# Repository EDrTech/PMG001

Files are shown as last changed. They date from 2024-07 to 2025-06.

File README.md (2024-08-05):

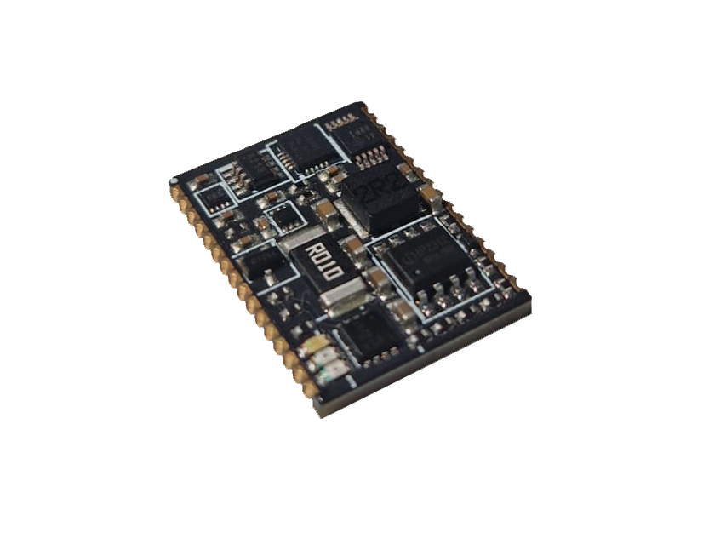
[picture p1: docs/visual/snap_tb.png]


# PMG001 Power management module

The PMG001 is a highly integrated module designed for efficient management of single-cell
Li-Po battery systems. It incorporates various essential ICs to address all aspects of power
management, including battery charging, switch/button power on/off behavior, undervoltage
and overvoltage protection, flexible voltage measurement, battery current measurement, and
temperature monitoring. Additionally, it features a microcontroller for programming custom
behaviors, ensuring comprehensive management of single-cell rechargeable battery
systems.
Furthermore, when paired with the demo kit base PCB, the module serves as a general
development board for the ATTINY1616, with all
1 pins accessible for any application.

## Features

- 32 PIN 22.22mm *16.51mm package
- On/off behavior control
- 2A single cell charger
- Single li-po cell powered
- 4+16 ADC channels
- Bi-directional battery current measurement
- Brown-out detection/reset circuit
- Low RDSon battery output MOSFET
- On-module temperature measurement
- I2C Interface
- Arduino compatible

## Installation

To program this module you will need the following:

- Arduino DE (Or other IDE of your choosing)
- [megaTinyCore](https://github.com/SpenceKonde/megaTinyCore)
- Demo kit with the module soldered on

There's no need to install any additional libraries as the example code only uses the wire library to handle I2C, the rest is in the [example](pmg001_default/pmg001_default.ino) code. Keep in mind that some register values are hardcoded, which is not the best way to handle something like that but is done here for the sake of simplicity. You can use external libraries with this module without issues, you just need to redefine I2C adresses of devices as they don't necessarily match with other libraries.

Board settings should be set up like this:

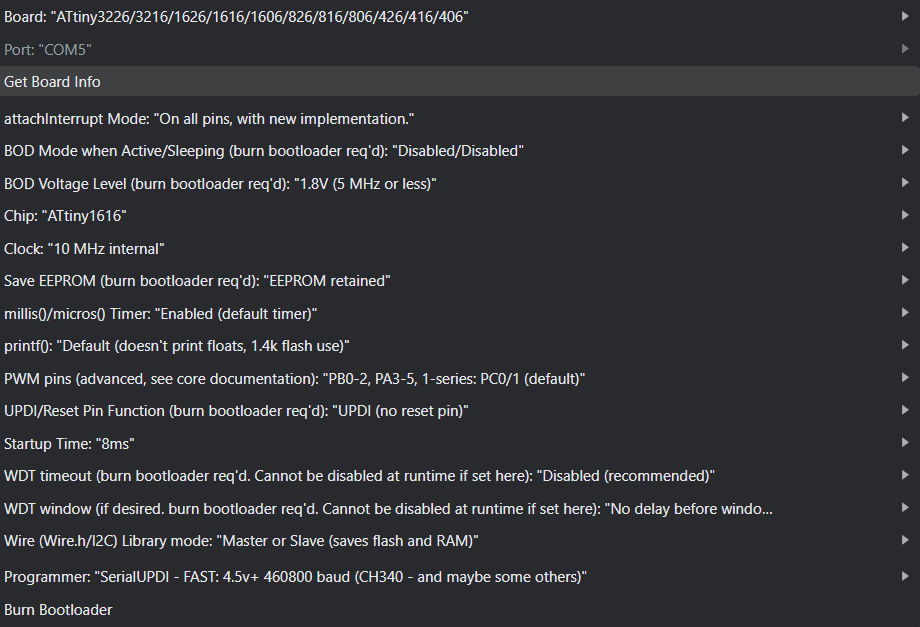
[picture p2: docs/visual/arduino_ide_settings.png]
Arduino IDE board settings


Default code provides basic power management and monitoring - press PWR_SW for >500ms and BAT_OUT will turn on, hold PWR_SW for >3s and BAT_OUT will turn off.

For more information, please read the [datasheet](PMG001_datasheet.pdf).

## Module Schematic

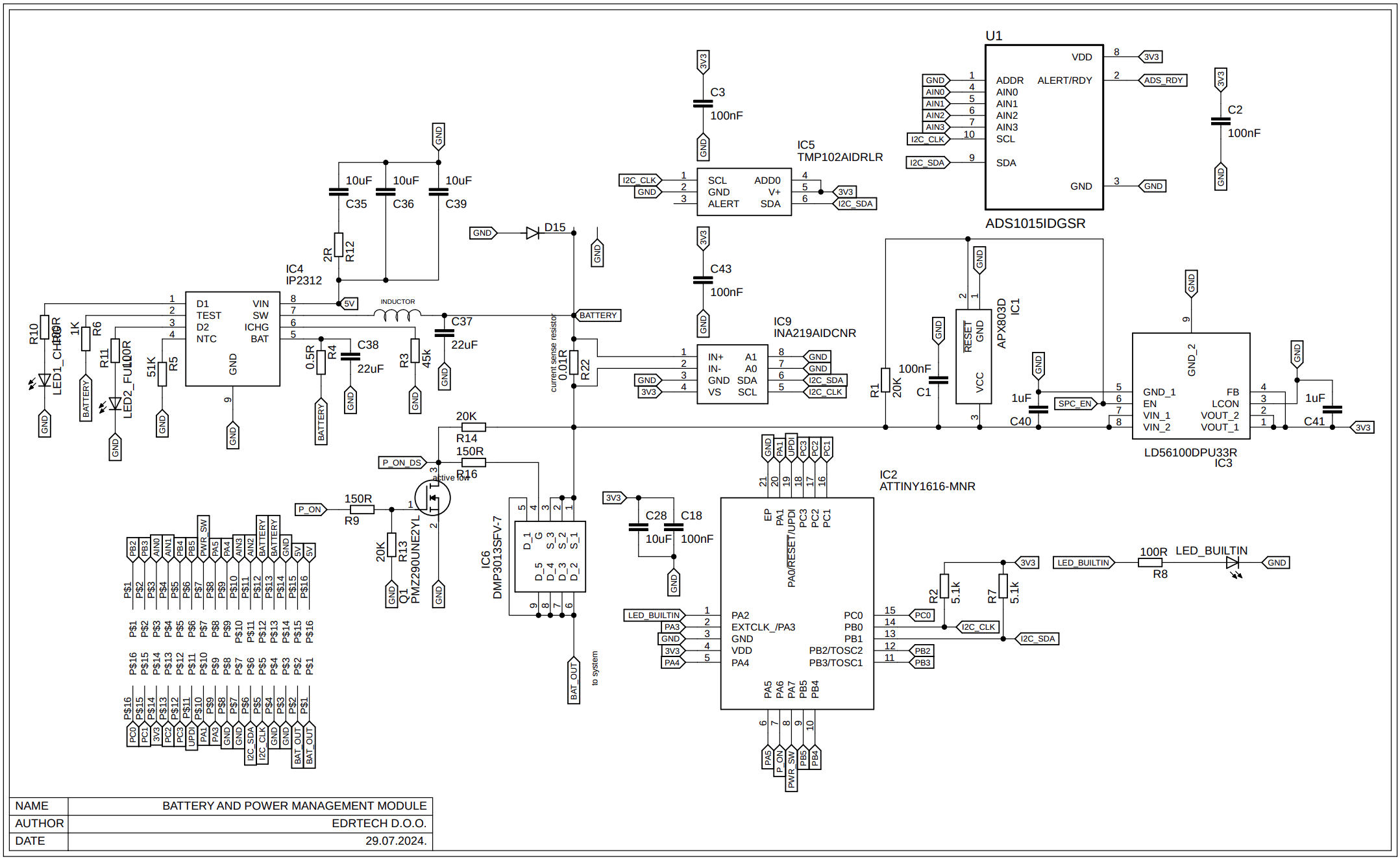
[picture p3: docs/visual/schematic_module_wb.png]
Module schematic


## Breakout board Schematic

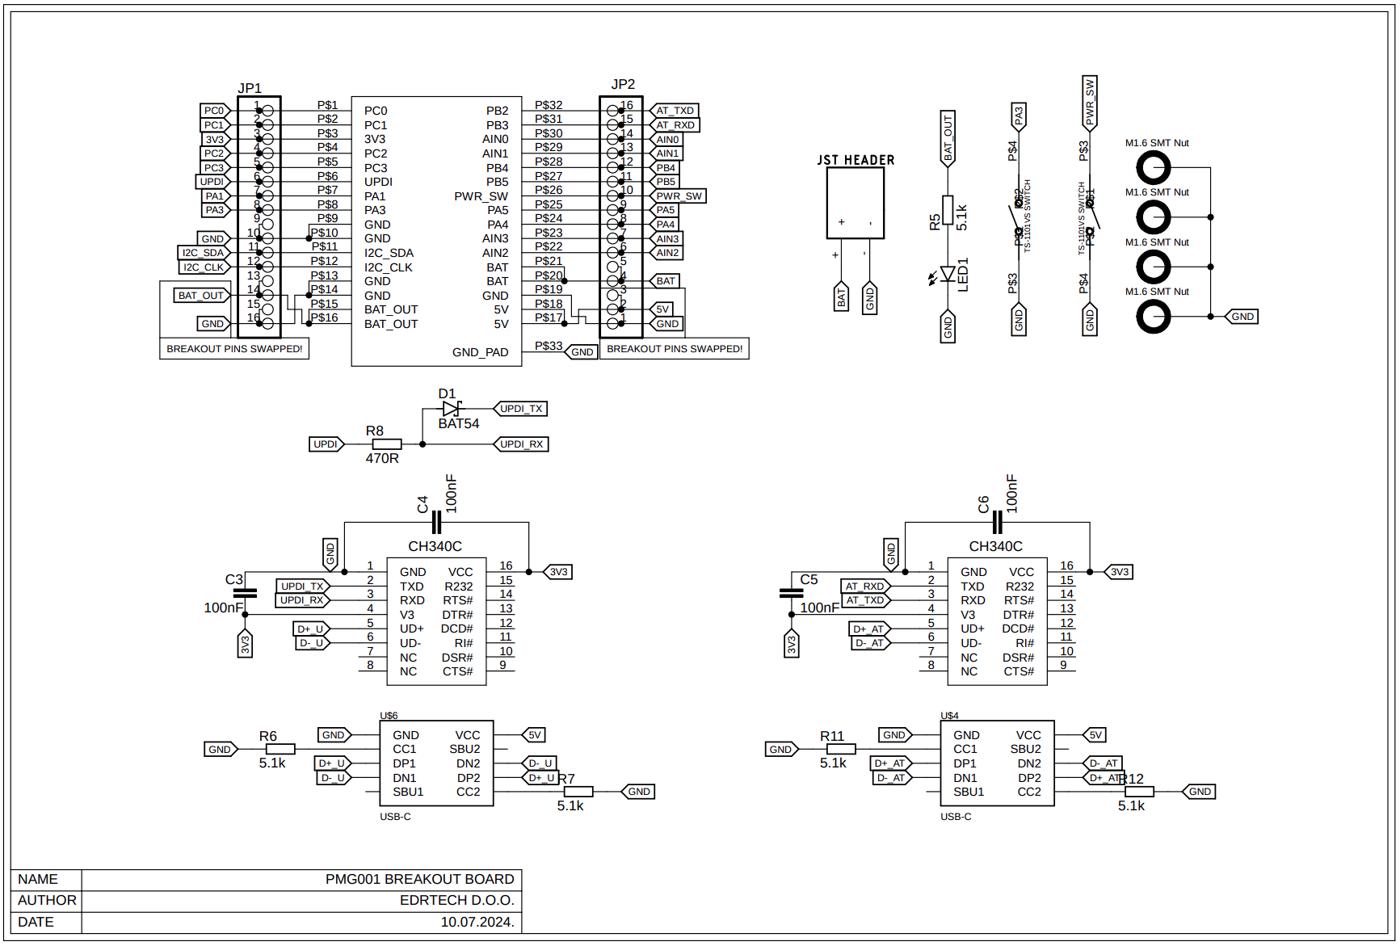
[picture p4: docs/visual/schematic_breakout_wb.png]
Breakout schematic


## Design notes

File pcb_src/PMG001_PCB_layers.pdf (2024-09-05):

PMG001 PCB Layers

# Top layer

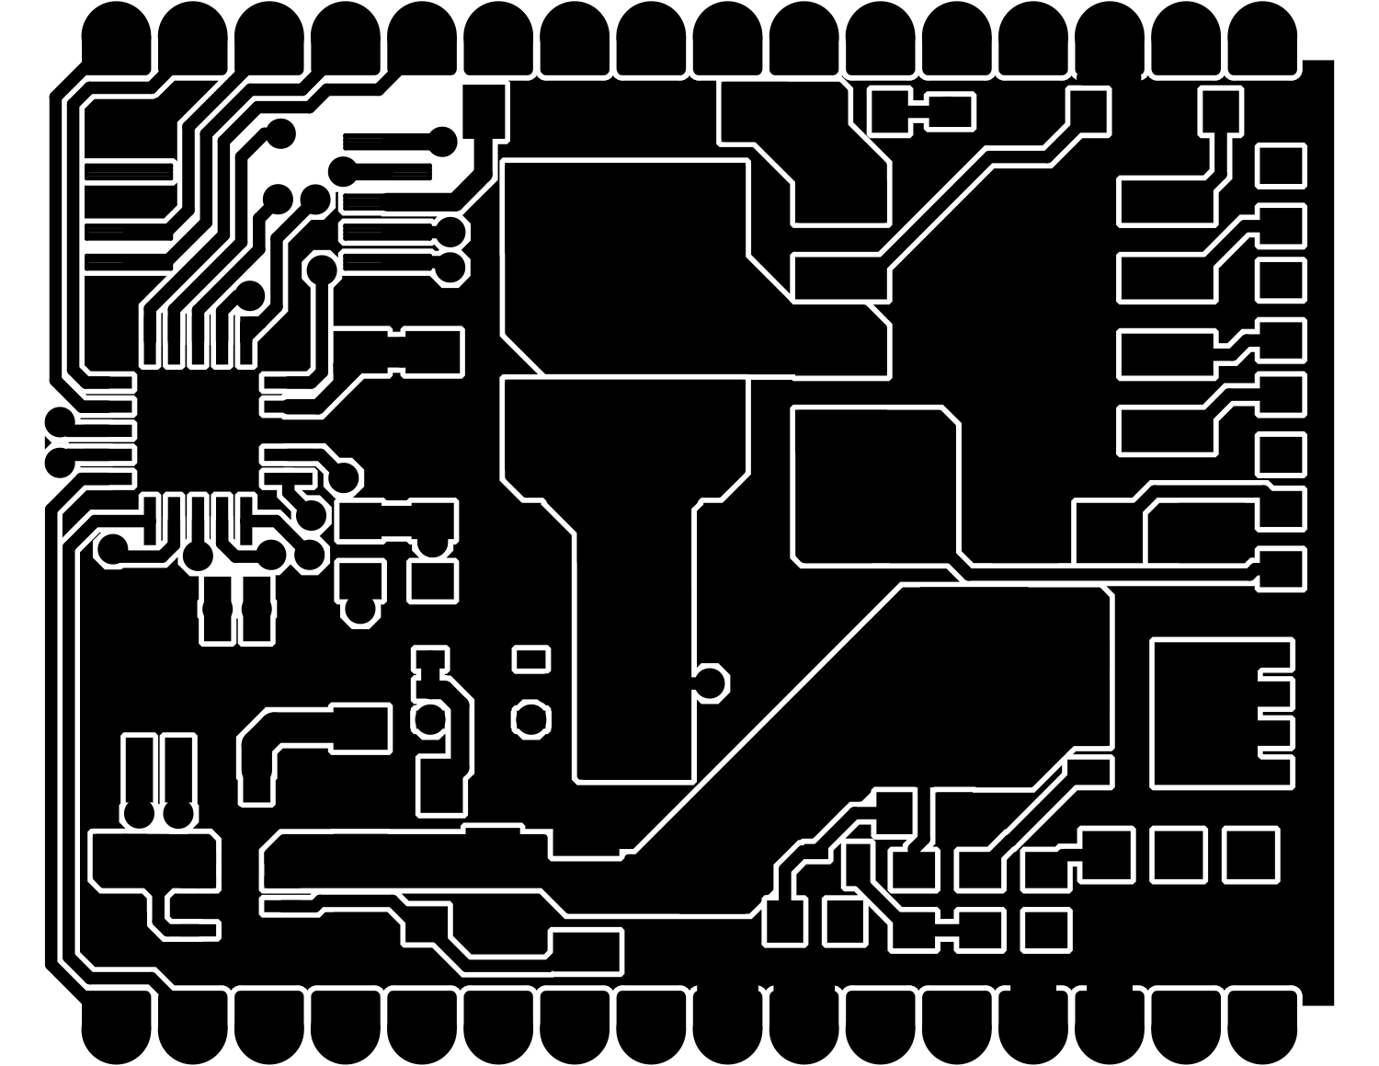
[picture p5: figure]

EDrTech d.o.o. 2024.

# Layer 2

# Layer 3

# Layer 4

# Layer 5

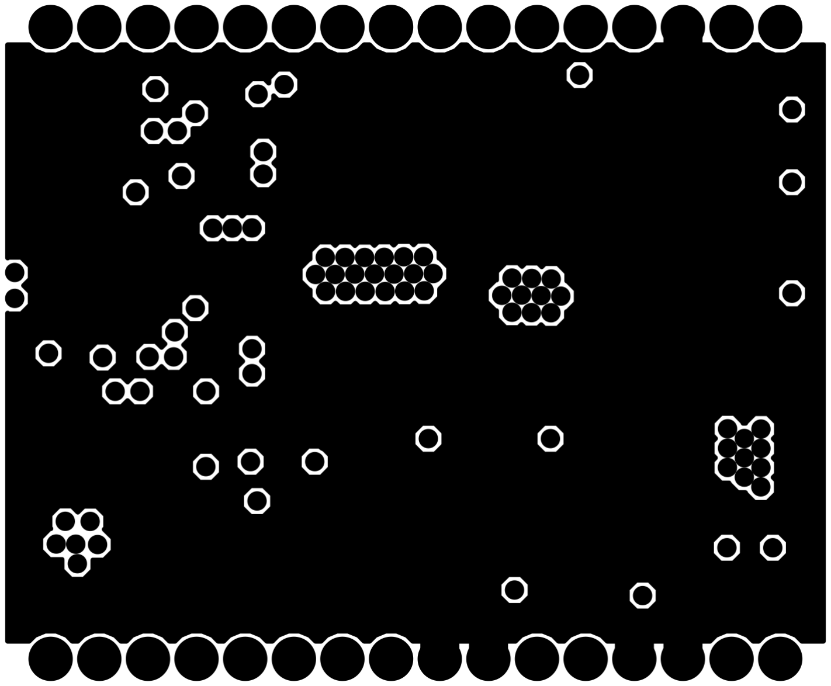
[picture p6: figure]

# Bottom layer

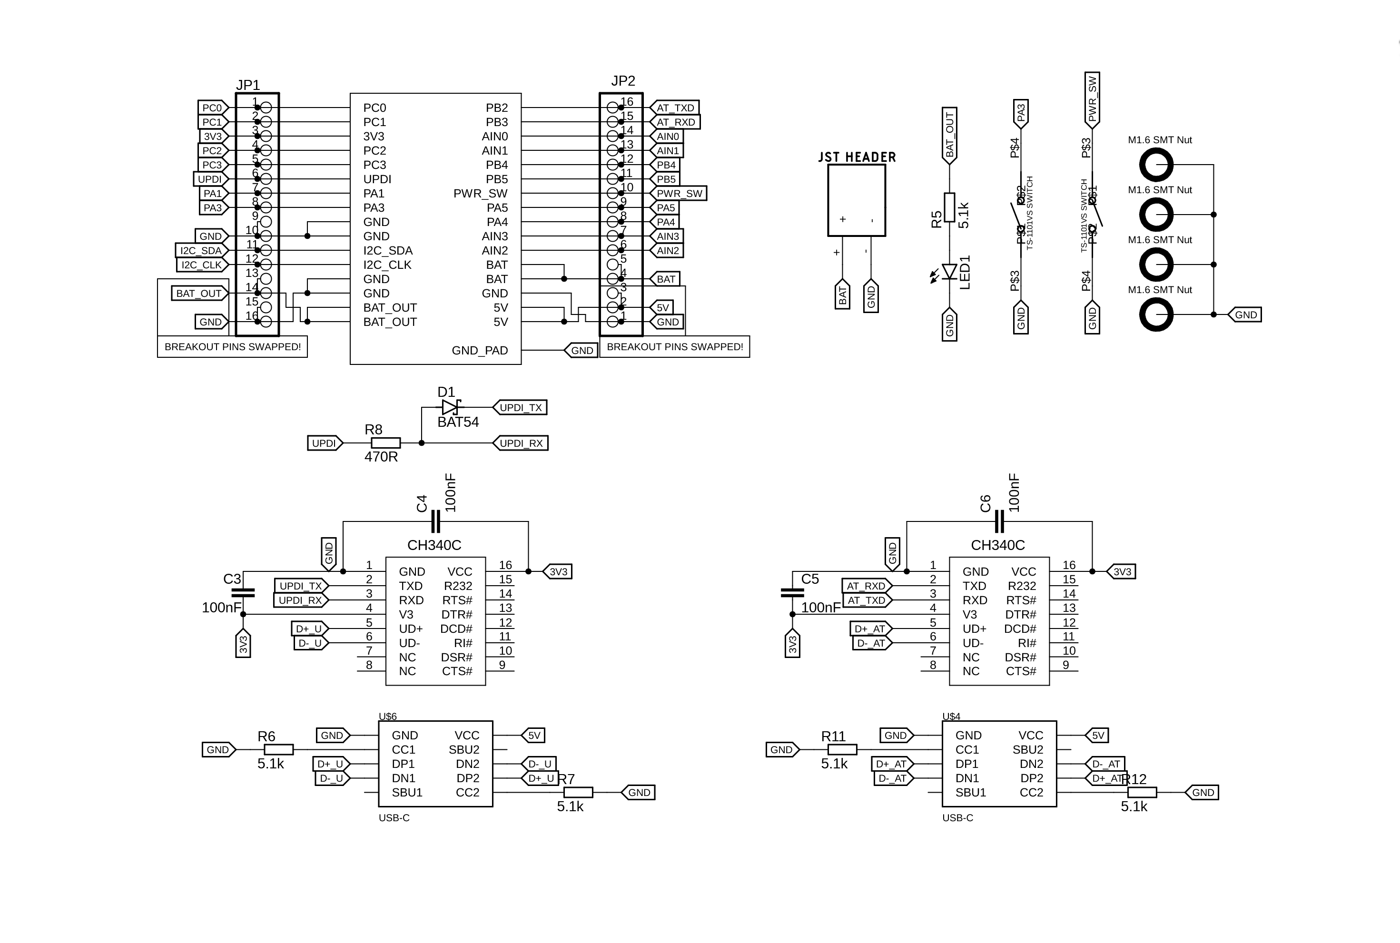
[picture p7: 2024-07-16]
docs/visual/dkit_PMG001_schematic.png

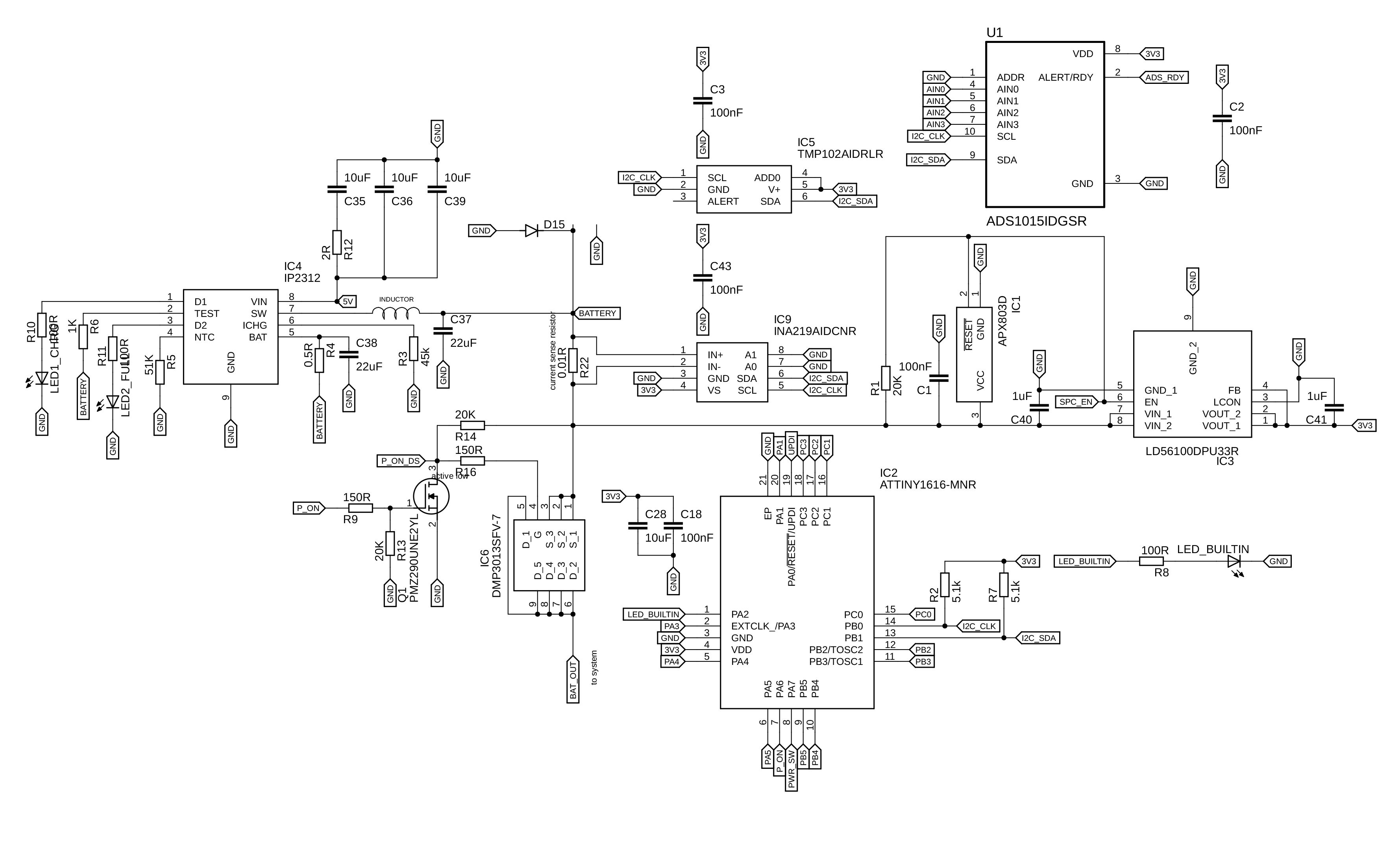
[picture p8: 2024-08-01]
docs/visual/module_schematic.png

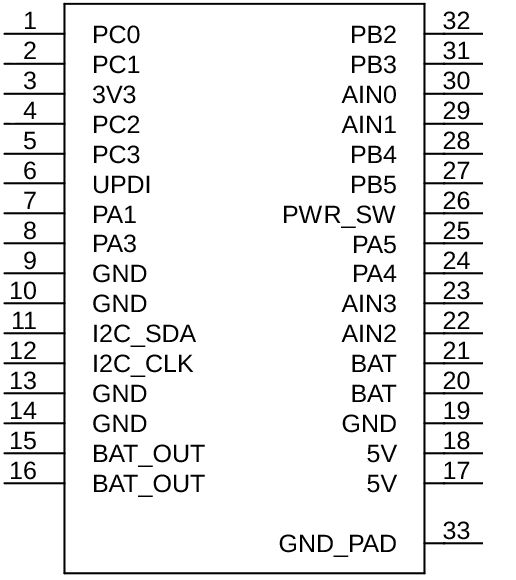
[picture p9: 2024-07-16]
docs/visual/symbol.png

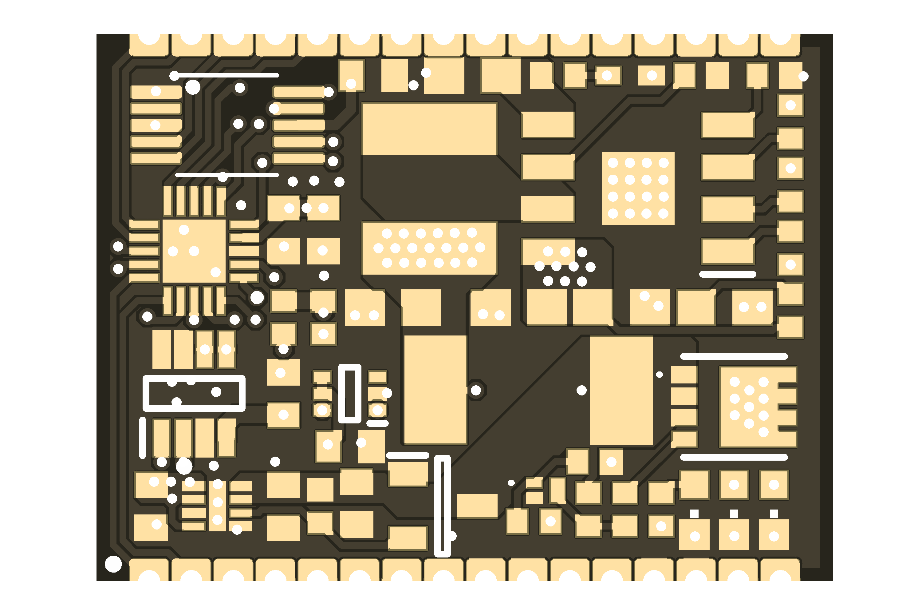
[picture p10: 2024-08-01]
docs/visual/pmg001_top.png

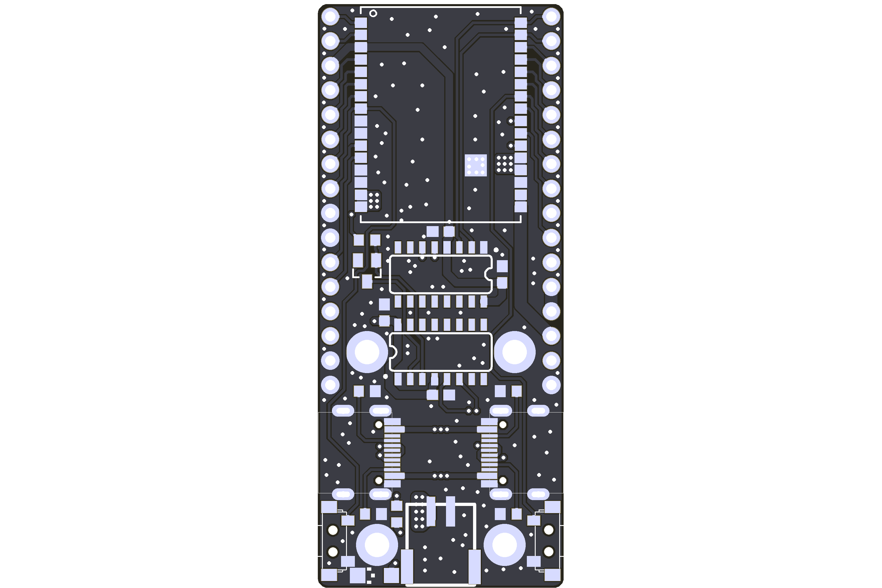
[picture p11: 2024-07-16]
docs/visual/breakout_pmg001_top.png

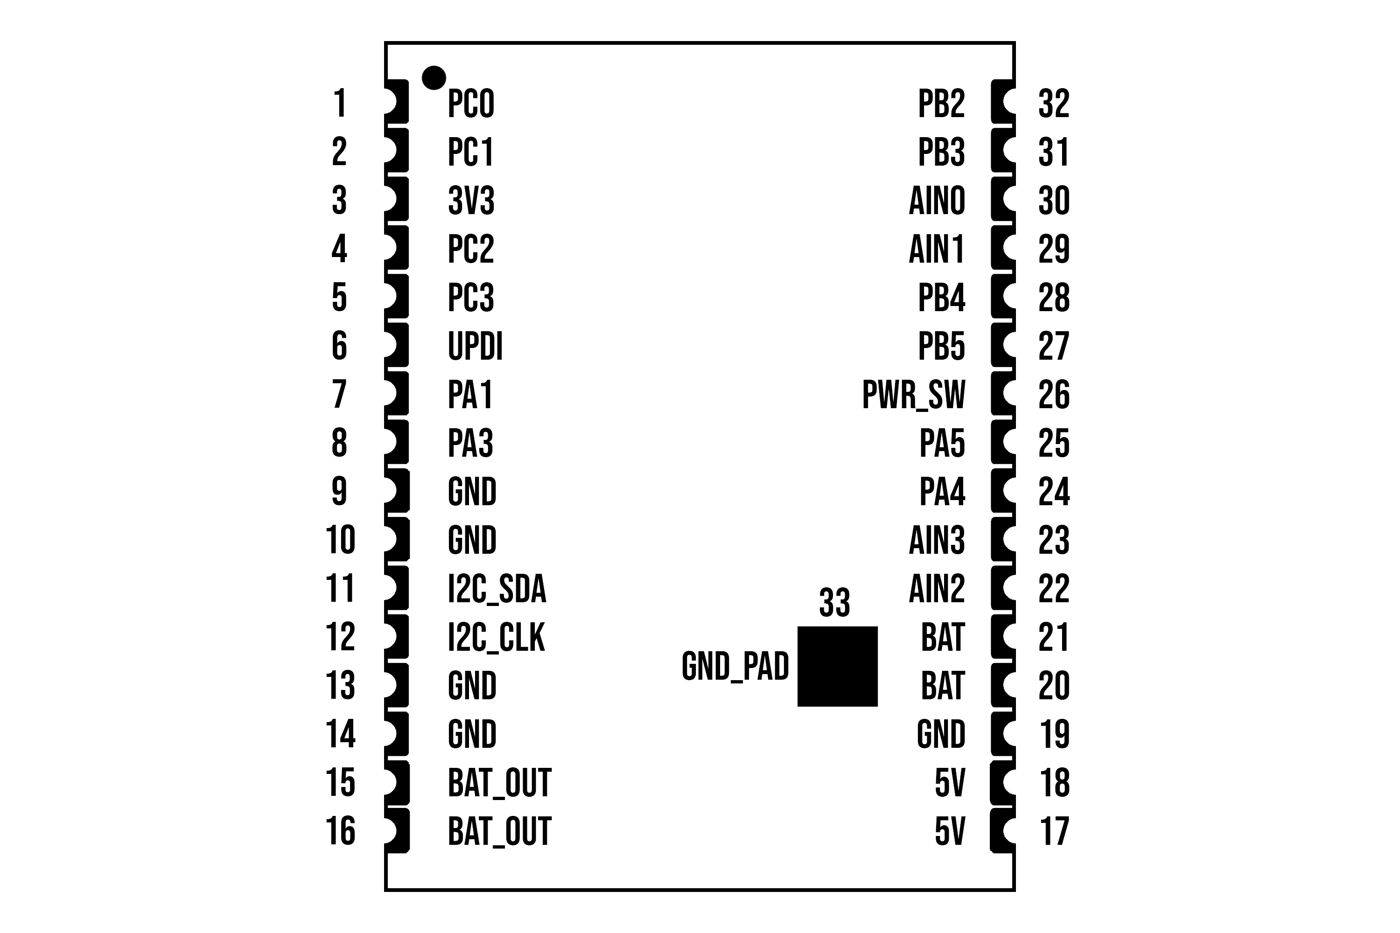
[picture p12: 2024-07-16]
docs/visual/pmg001_top_pins.png

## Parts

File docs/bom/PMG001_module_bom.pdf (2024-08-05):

PMG001 Module BOM & Part sheet

EDrTech d.o.o. 2024.

Part name | Qty | Package | Parts
0.01R | 1 | 2512 | R22
0.5R | 1 | 0402 | R4
2R | 1 | 0402 | R12
100R | 3 | 0402 | R8, R10, R11
150R | 2 | 0402 | R16
1K | 1 | 0402 | R6
5.1K | 2 | 0402 | R2, R7
20K | 3 | 0402 | R1, R14
51K | 1 | 0402 | R5
45K | 1 | 0402 | R3
100nF | 5 | 0402 | C1, C2, C3, C18, C43
1uF | 2 | 0402 | C40, C41
10uF | 1 | 0402 | C28
10uF | 3 | 0603 | C35, C36, C39
22uF | 2 | 0603 | C37, C38
YSMC0420V-2R2M | 1 | 4.2x4.2mm | U$91
XL-1608SURC-06 | 1 | 0603 | LED1_CHRG
XL-1608SYGC-06 | 1 | 0603 | LED2_FULL
XL-1608UBC-04 | 1 | 0603 | LED_BUILTIN
LESD5Z5.0CT1G | 1 | SOD-523 | D15
PMZ290UNE2YL | 1 | SOT-883-3 | Q1
ATTINY1616-MNR | 1 | QFN-20-EP(3x3) | IC2
ADS1015IDGSR | 1 | VSSOP-10-0.5mm | U1
APX803-31SAG-7 | 1 | SOT-23 | IC1
DMP3013SFV-7 | 1 | PowerDI3333-8 | IC6
INA219AIDCNR | 1 | SOT-23-8 | IC9
IP2312 | 1 | ESOP-8 | IC4
LD56100DPU33R | 1 | DFN-8(1.2x1.6) | IC3
TMP102AIDRLR | 1 | SOT-563 | IC5

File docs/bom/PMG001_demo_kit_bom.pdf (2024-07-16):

PMG001 Module Demo kit BOM & Part sheet

EDrTech d.o.o. 2024.

Part name | Qty | Package | Parts
470R | 1 | 0603 | R8
5.1K | 5 | 0603 | R5, R6, R7, R11, R12
100nF | 4 | 0603 | C3, C4, C5, C6
BAT54 | 1 | SOT-23 | D1
XL-3216UWC | 1 | 1206 | LED1
PMG001 | 1 | 22.22mm *16.51mm | U$7
CH340C | 2 | SOP-16 | U$1, U$5
TS-1101VS-C-A-A | 2 | 3.5mm*7.8mm | U$2, U$3
USB-C | 2 | | U$4, U$6
JST 2 pin 2mm | 1 | | JSTCON
SMTSO1630 | 4 | | U$8, U$9, U$10, U$11

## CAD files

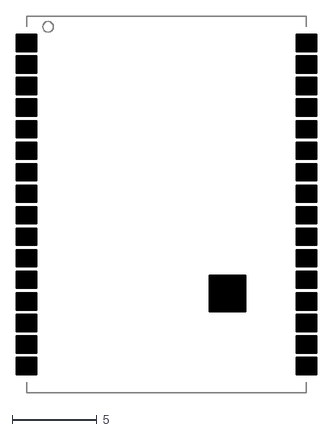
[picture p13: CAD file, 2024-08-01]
docs/visual/footprint_Model.dxf
17.7 x 22.2

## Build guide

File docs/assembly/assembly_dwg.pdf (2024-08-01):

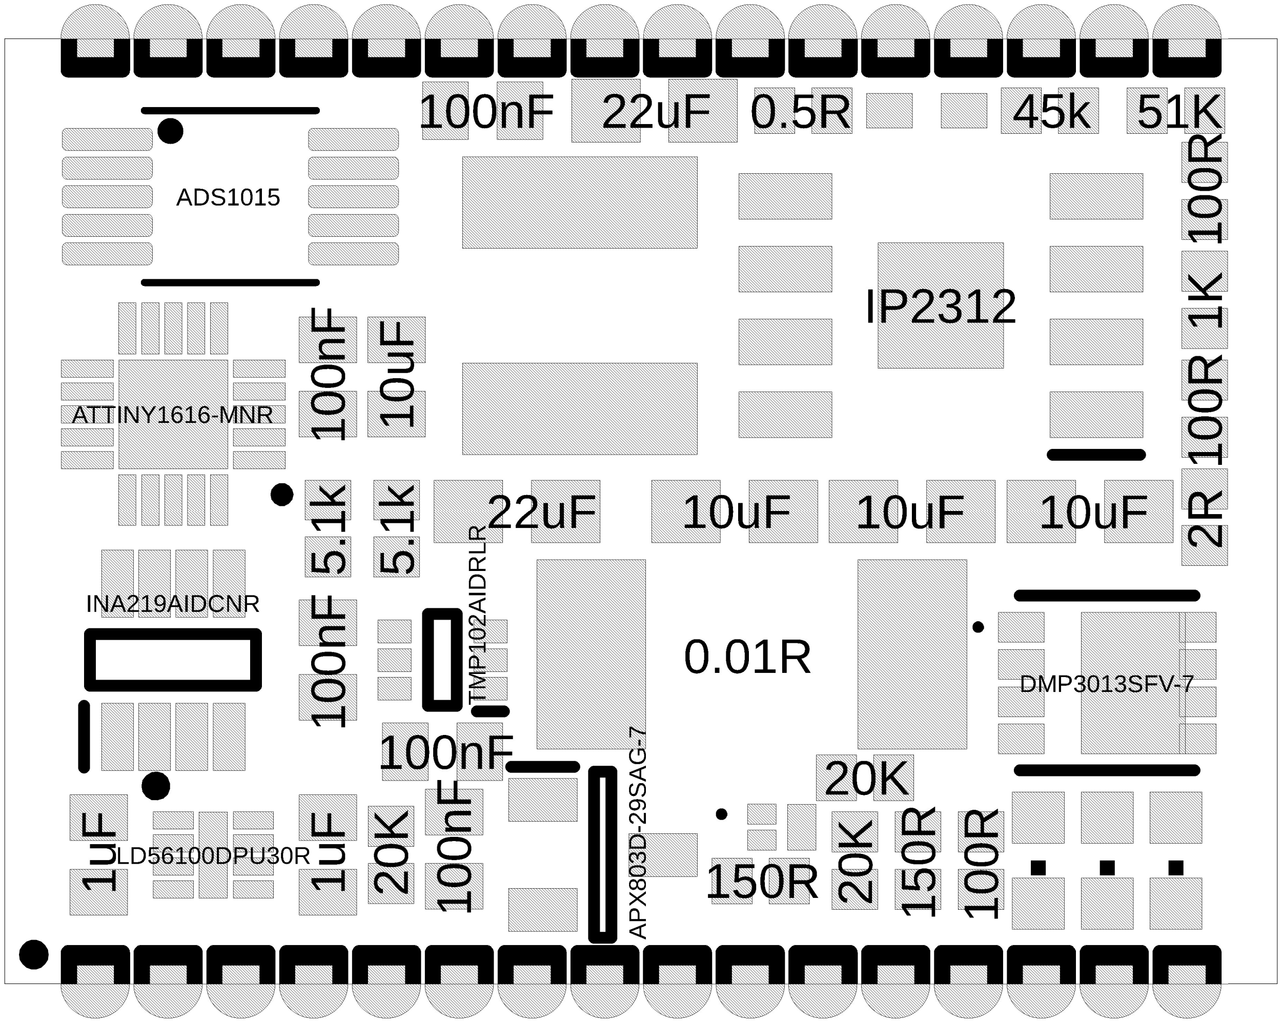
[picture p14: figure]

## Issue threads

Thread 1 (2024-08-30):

Some Comments and Vuestions

Kabron287, 2024-08-30:
"Battery charging is automatically managed by the IP2312 IC, which can provide up to 2A charging current to the battery. **This current is not adjustable**"

- Very bad.

What is current consumption of the module?

EDrTech, 2024-08-30:
Well, charging current is set by resistors on the module, so it can be configured, but not easily changed once it's mounted on a PCB. I use 2C batteries with min 1000mAh at least so I set the current to my liking, since this is open source, anyone is free to set it as they please.

Current consumption is 13mA when cpu is awake, and around 0.1mA when sleeping, this is with 2x ch340c operating current calculated in, without those it would very likely be significantly smaller. Of course, when charging the battery the current can go up to 2A

Kabron287, 2024-08-30:
When uC is in sleep state all monitoring cancelled, so coulomb counter stop working and capacity data lost?
If, so what is the practical use of this device?

EDrTech, 2024-08-30:
Attiny1616 enters sleep mode (standby to be exact), no data is lost. The core is in standby mode but peripherals are still running (so IO state doesn't change on entering/exiting sleep). In the default firmware it wakes up once a second to take measurements, prints to serial and goes back to sleep until RTC raises the interrupt event again.

It is planned to implement an additional I2C interface on free pins so it can send/receive data from the host uC in the near future. This is a firmware feature for which the hardware is already configured.

Closed 2024-08-30.

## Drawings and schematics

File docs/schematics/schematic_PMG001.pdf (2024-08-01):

C2 ADDR 1 | AIN0 4 | AIN1 5 | AIN2 6 | AIN3 7 | SCL 10 | SDA 9 | VDD | 8 ALERT/RDY | 2 GND | 3 U1 GND

C3

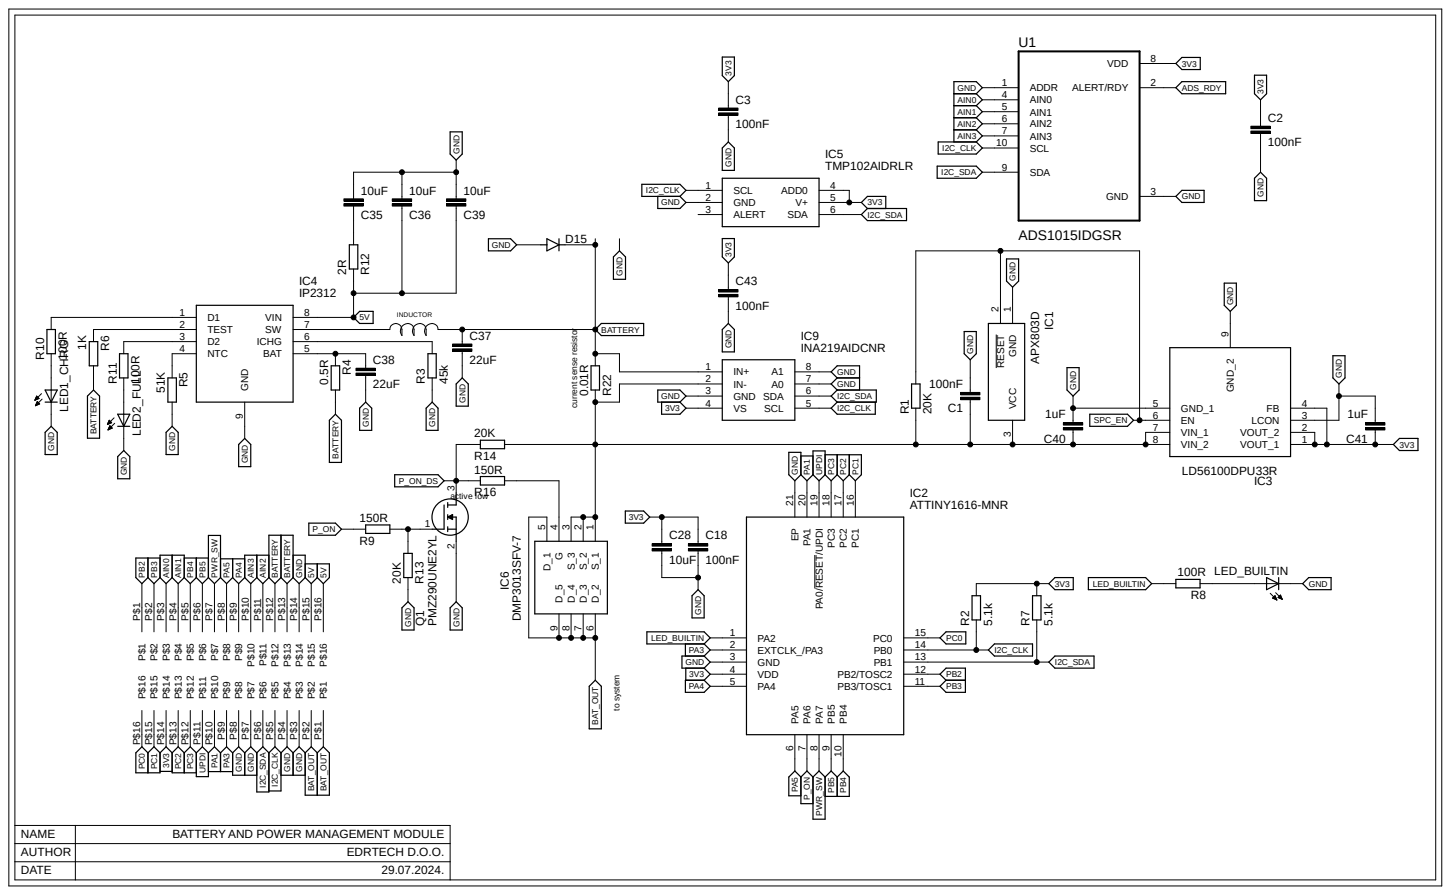
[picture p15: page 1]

NAME | BATTERY AND POWER MANAGEMENT MODULE
AUTHOR | EDRTECH D.O.O.
DATE | 29.07.2024.

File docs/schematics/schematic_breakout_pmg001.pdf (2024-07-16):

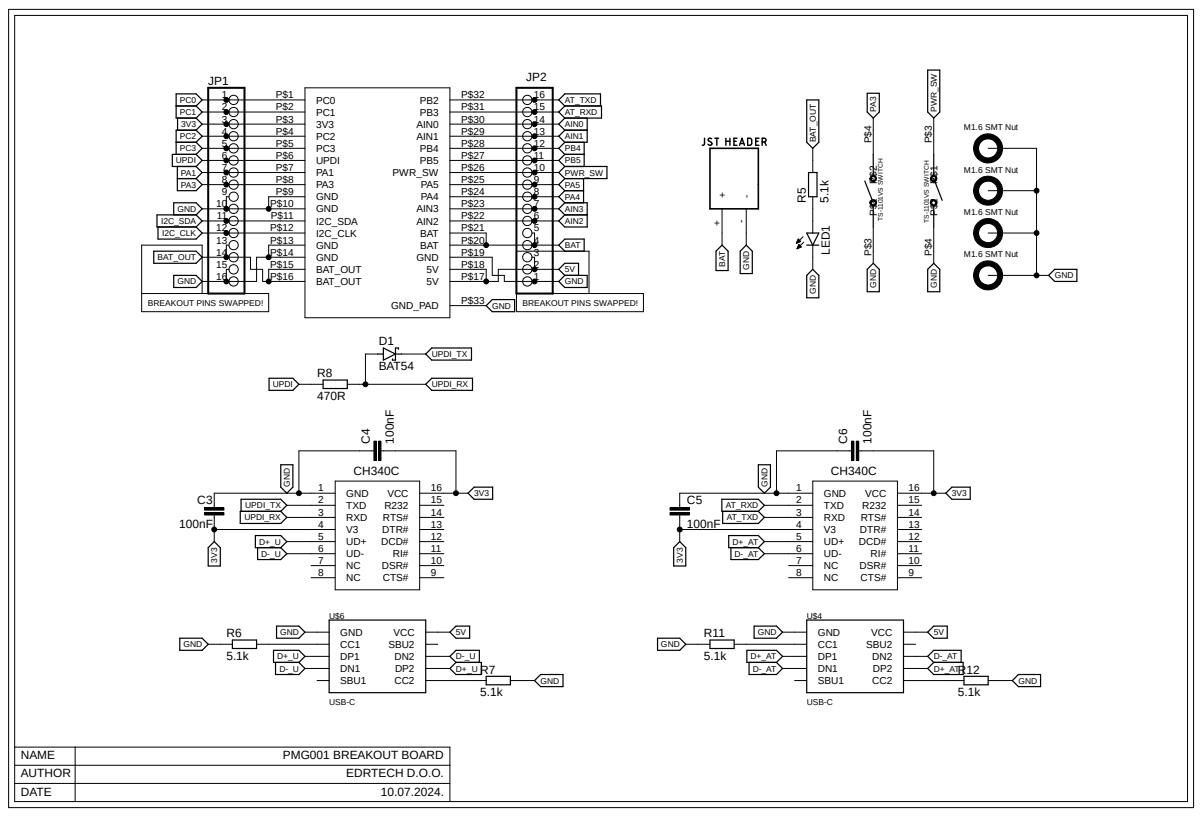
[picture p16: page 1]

2 | 15
3 | 14
4 | 13
5 | 12

7 | 10

11 | 6
12 | 5
13

NAME | PMG001 BREAKOUT BOARD
AUTHOR | EDRTECH D.O.O.
DATE | 10.07.2024.

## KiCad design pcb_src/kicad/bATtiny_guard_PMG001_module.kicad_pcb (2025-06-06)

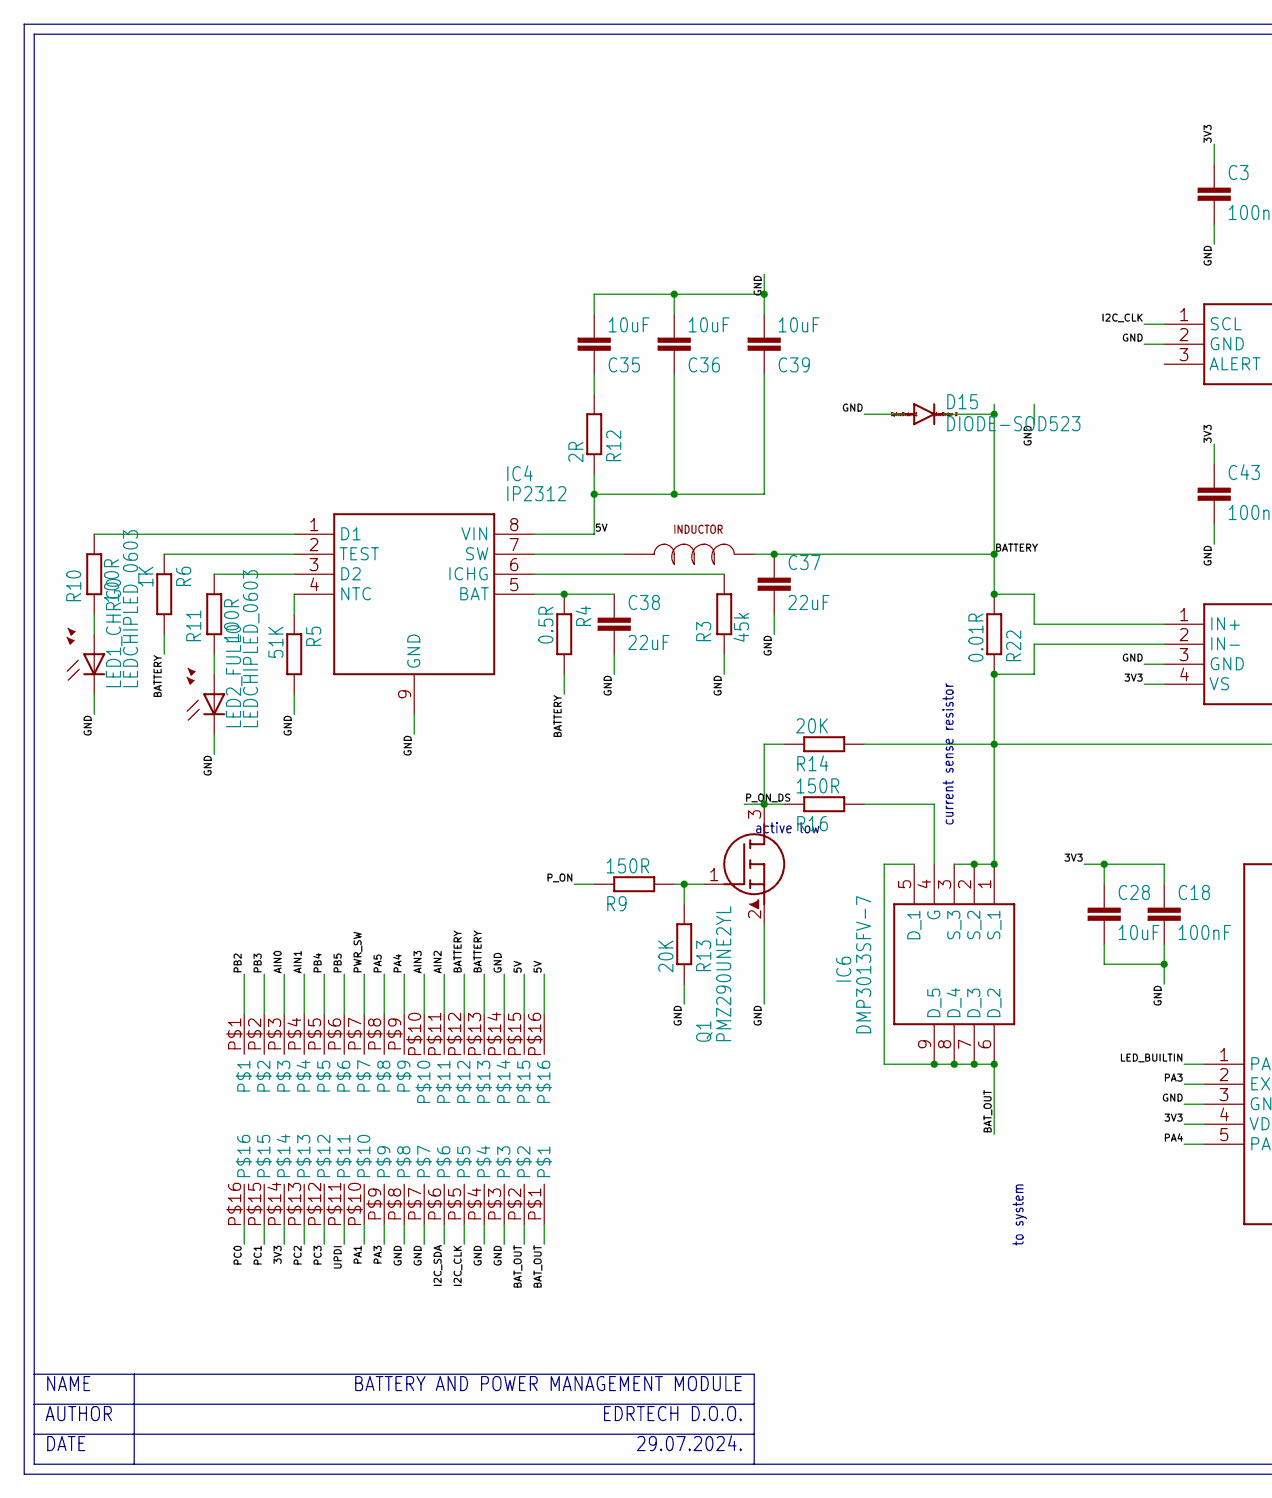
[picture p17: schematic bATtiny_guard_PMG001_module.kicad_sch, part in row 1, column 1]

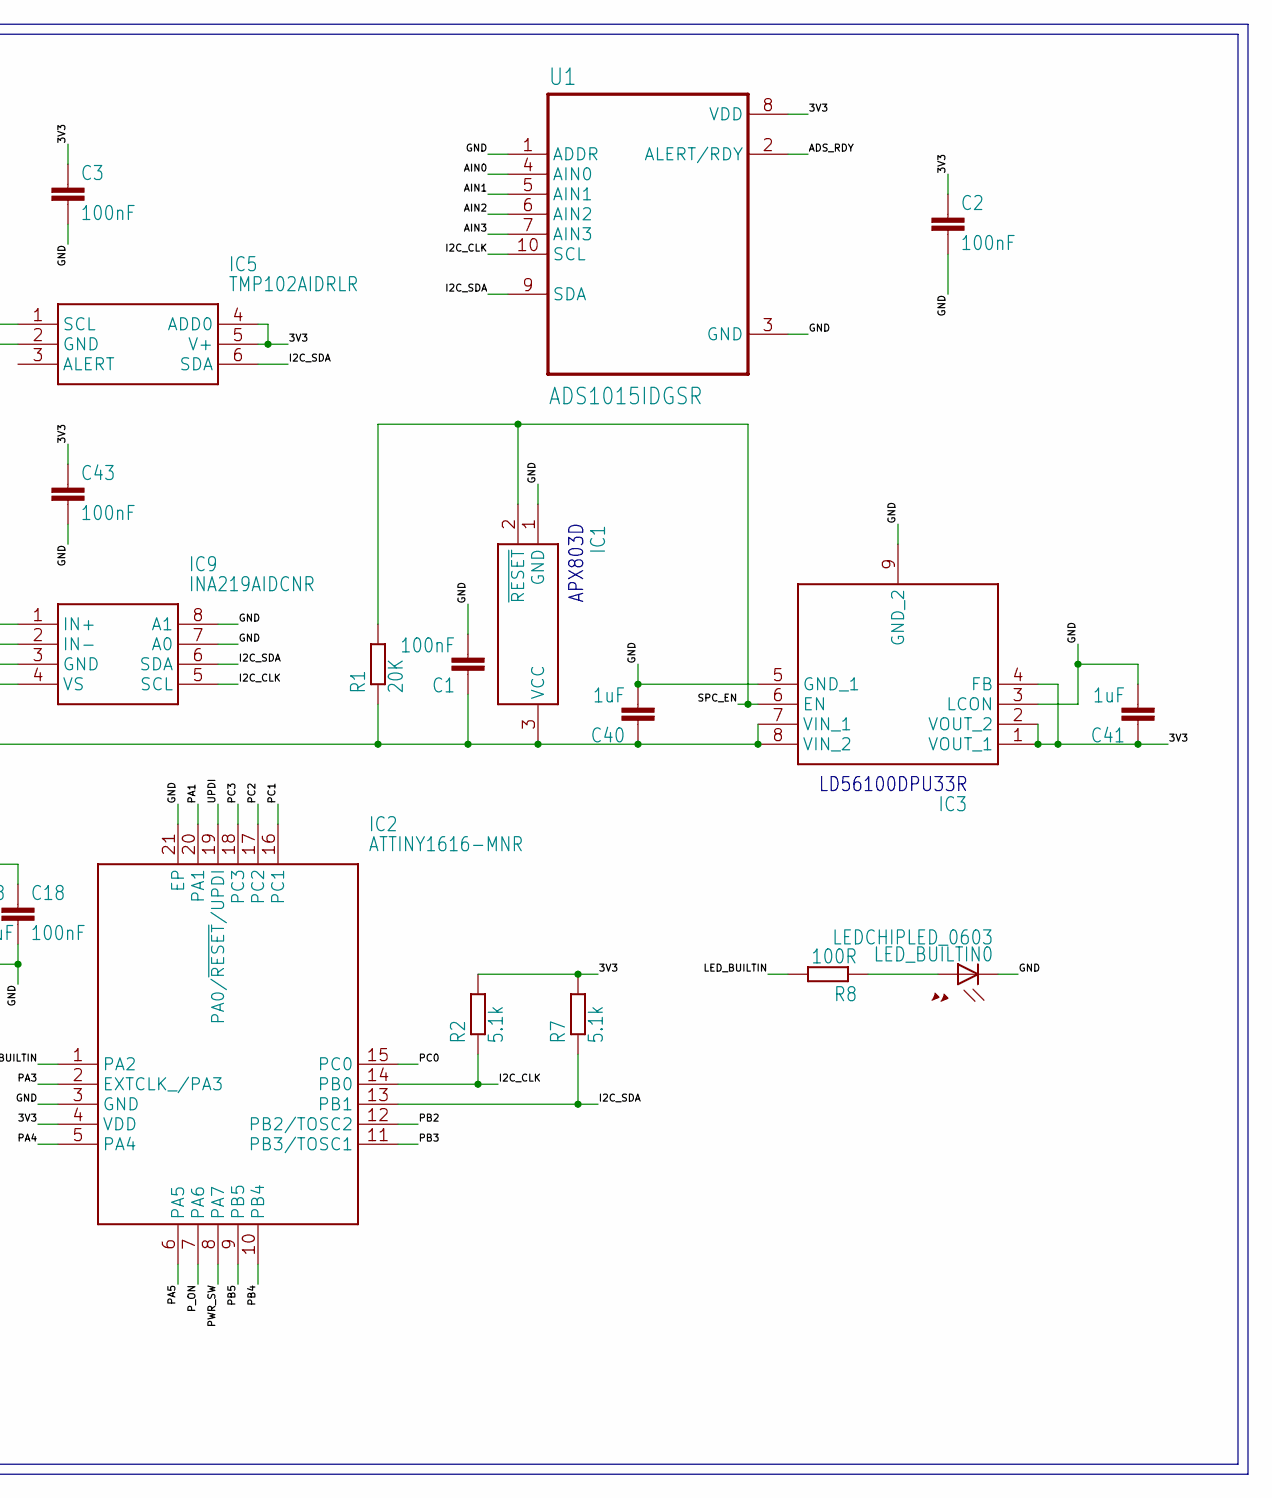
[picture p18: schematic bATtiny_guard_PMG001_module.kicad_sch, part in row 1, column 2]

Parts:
C1, C2, C3, C18, C43: 100nF; C0402
C28: 10uF; C0402
C35, C36, C39: 10uF; C0603
C37, C38: 22uF; C0603
C40, C41: 1uF; C0402
D15: DIODE-SOD523; SOD523
IC1: APX803D-29SAG-7; SOT96P240X110-3N
IC2: ATTINY1616-MNR; QFN40P300X300X90-21N
IC3: LD56100DPU30R; SON40P120X160X50-9N
IC4: IP2312; SOIC127P600X165-9N
IC5: TMP102AIDRLR; SOTFL50P160X60-6N
IC6: DMP3013SFV-7; DMP3036SFV7
IC9: INA219AIDCNR; SOP65P280X145-8N
LED1_CHRG0, LED2_FULL0: LEDCHIPLED_0603; CHIPLED_0603
LED_BUILTIN0: LEDCHIPLED_0603; CHIPLED_0603
Q1: PMZ290UNE2YL
R1, R13, R14: 20K; R0402
R2, R7: 5.1k; R0402
R3: 45k; R0402
R4: 0.5R; R0402
R5: 51K; R0402
R6: 1K; R0402
R8, R10, R11: 100R; R0402
R9, R16: 150R; R0402
R12: 2R; R0402
R22: 0.01R; R2512
U1: ADS1015IDGSR; SOP50P490X110-10N
U$1, U$2: 1.27_MALE_16P_HEADER
U$91: 1uH; NRS5040T3R3NMGJ

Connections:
3V3: C2.1, C3.1, C18.1, C28.1, C41.1, C43.1, IC2.4 (VDD), IC3.1 (VOUT_1), IC3.2 (VOUT_2), IC3.4 (FB), IC5.4 (ADD0), IC5.5 (V+), IC9.4 (VS), R2.2, R7.2, U1.8 (VDD), U$2.P$14
5V: C36.1, C39.1, IC4.8 (VIN), R12.1, U$1.P$15, U$1.P$16
ADS_RDY: U1.2 (ALERT/RDY)
AIN0: U1.4 (AIN0), U$1.P$3
AIN1: U1.5 (AIN1), U$1.P$4
AIN2: U1.6 (AIN2), U$1.P$11
AIN3: U1.7 (AIN3), U$1.P$10
BATTERY: C37.1, D15.C, IC9.1 (IN+), R4.2, R6.2, R22.2, U$1.P$12, U$1.P$13, U$91.P$1
BAT_OUT: IC6.5 (D_1), IC6.6 (D_2), IC6.7 (D_3), IC6.8 (D_4), IC6.9 (D_5), U$2.P$1, U$2.P$2
BTAP: C1.1, C40.1, IC1.3 (VCC), IC3.7 (VIN_1), IC3.8 (VIN_2), IC6.1 (S_1), IC6.2 (S_2), IC6.3 (S_3), IC9.2 (IN-), R1.1, R14.2, R22.1
GND: C1.2, C2.2, C3.2, C18.2, C28.2, C35.2, C36.2, C37.2, C38.2, C39.2, C40.2, C41.2, C43.2, D15.A, IC1.1 (GND), IC2.3 (GND), IC2.21 (EP), IC3.3 (LCON), IC3.5 (GND_1), IC3.9 (GND_2), IC4.9 (GND), IC5.2 (GND), IC9.3 (GND), IC9.7 (A0), IC9.8 (A1), LED1_CHRG0.C, LED2_FULL0.C, LED_BUILTIN0.C, Q1.2 (S), R3.1, R5.2, R13.1, U1.1 (ADDR), U1.3 (GND), U$1.P$14, U$2.P$3, U$2.P$4, U$2.P$7, U$2.P$8
I2C_CLK: IC2.14 (PB0), IC5.1 (SCL), IC9.5 (SCL), R2.1, U1.10 (SCL), U$2.P$5
I2C_SDA: IC2.13 (PB1), IC5.6 (SDA), IC9.6 (SDA), R7.1, U1.9 (SDA), U$2.P$6
LED_BUILTIN: IC2.1 (PA2), R8.2
unnamed: Q1.1 (G), R9.2, R13.2
unnamed: LED_BUILTIN0.A, R8.1
unnamed: IC6.4 (G), R16.2
unnamed: IC4.6 (ICHG), R3.2
unnamed: C35.1, R12.2
unnamed: LED1_CHRG0.A, R10.1
unnamed: LED2_FULL0.A, R11.1
unnamed: IC4.4 (NTC), R5.1
unnamed: IC4.2 (TEST), R6.1
unnamed: IC4.1 (D1), R10.2
unnamed: IC4.3 (D2), R11.2
unnamed: C38.1, IC4.5 (BAT), R4.1
unnamed: IC4.7 (SW), U$91.P$2
PA1: IC2.20 (PA1), U$2.P$10
PA3: IC2.2 (EXTCLK_/PA3), U$2.P$9
PA4: IC2.5 (PA4), U$1.P$9
PA5: IC2.6 (PA5), U$1.P$8
PB2: IC2.12 (PB2/TOSC2), U$1.P$1
PB3: IC2.11 (PB3/TOSC1), U$1.P$2
PB4: IC2.10 (PB4), U$1.P$5
PB5: IC2.9 (PB5), U$1.P$6
PC0: IC2.15 (PC0), U$2.P$16
PC1: IC2.16 (PC1), U$2.P$15
PC2: IC2.17 (PC2), U$2.P$13
PC3: IC2.18 (PC3), U$2.P$12
PWR_SW: IC2.8 (PA7), U$1.P$7
P_ON: IC2.7 (PA6), R9.1
P_ON_DS: Q1.3 (D), R14.1, R16.1
SPC_EN: IC1.2 (~RESET), IC3.6 (EN), R1.2
UPDI: IC2.19 (PA0/~RESET/UPDI), U$2.P$11

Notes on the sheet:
current sense resistor
AUTHOR
APX803D
active low
LD56100DPU33R
EDRTECH D.O.O.
NAME
DATE
BATTERY AND POWER MANAGEMENT MODULE
to system
29.07.2024.

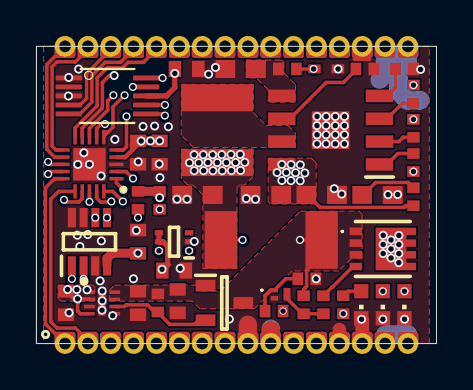
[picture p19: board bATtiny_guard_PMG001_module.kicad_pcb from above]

Board: 6 copper layers, 22.2 x 16.5 mm, 45 parts (0 on the bottom side), 43 nets.

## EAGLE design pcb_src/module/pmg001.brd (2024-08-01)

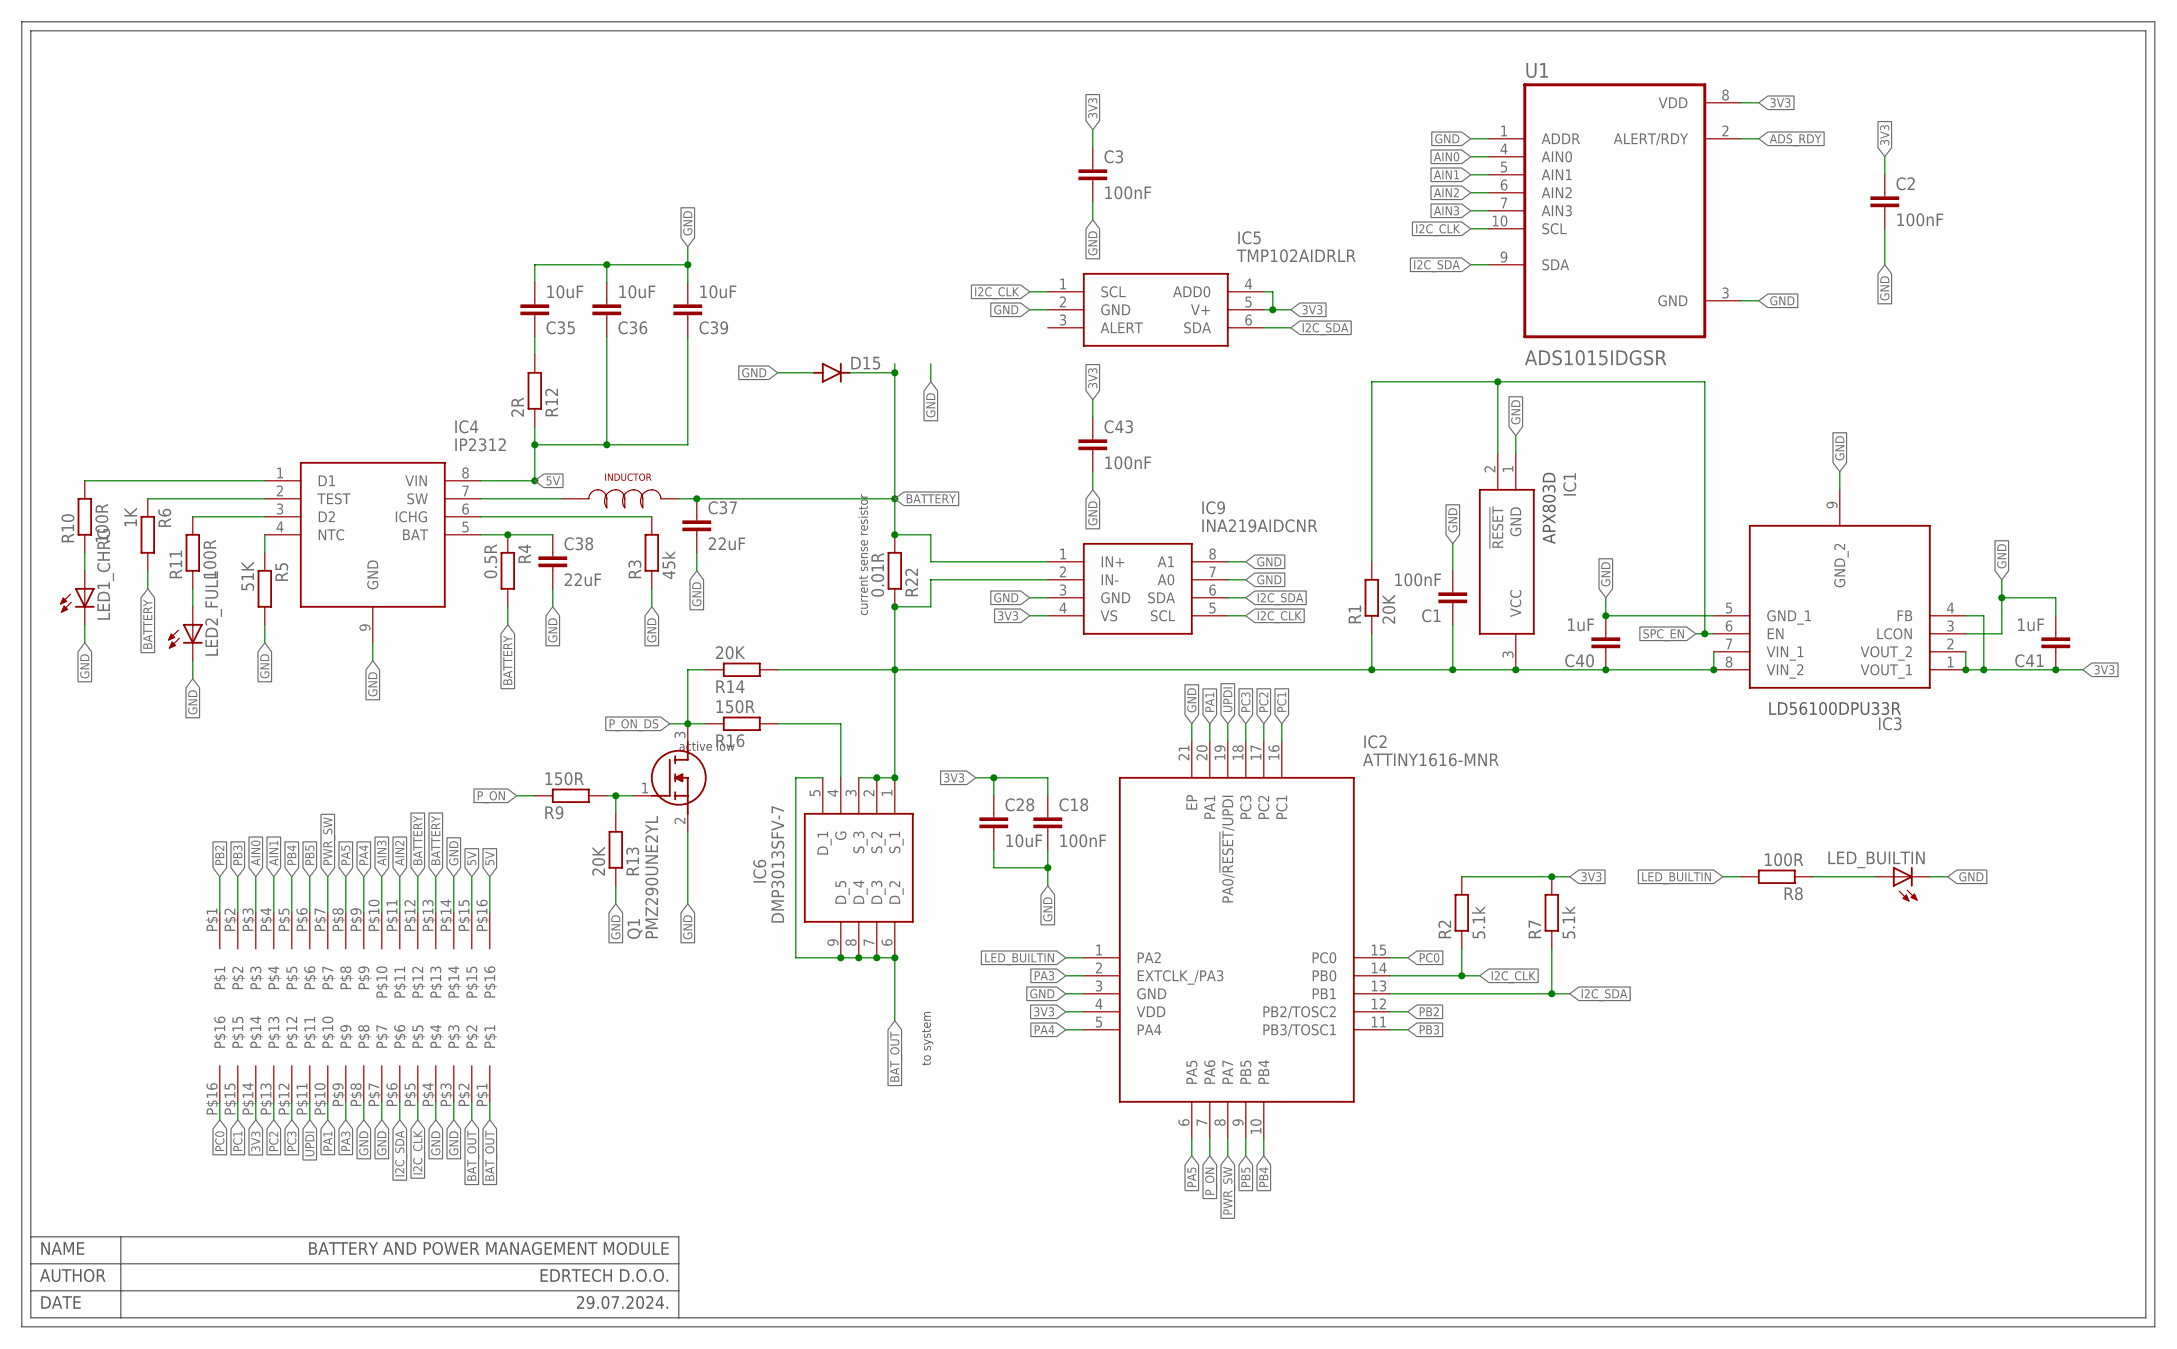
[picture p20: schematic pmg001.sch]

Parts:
C1, C2, C3, C18, C43: 100nF; C0402
C28: 10uF; C0402
C35, C36, C39: 10uF; C0603
C37, C38: 22uF; C0603
C40, C41: 1uF; C0402
D15: DIODE-SOD523; SOD523
IC1: APX803D-29SAG-7; SOT96P240X110-3N
IC2: ATTINY1616-MNR; QFN40P300X300X90-21N
IC3: LD56100DPU30R; SON40P120X160X50-9N
IC4: IP2312; SOIC127P600X165-9N
IC5: TMP102AIDRLR; SOTFL50P160X60-6N
IC6: DMP3013SFV-7; DMP3036SFV7
IC9: INA219AIDCNR; SOP65P280X145-8N
LED1_CHRG, LED2_FULL: LEDCHIPLED_0603; CHIPLED_0603
LED_BUILTIN: LEDCHIPLED_0603; CHIPLED_0603
Q1: PMZ290UNE2YL
R1, R13, R14: 20K; R0402
R2, R7: 5.1k; R0402
R3: 45k; R0402
R4: 0.5R; R0402
R5: 51K; R0402
R6: 1K; R0402
R8, R10, R11: 100R; R0402
R9, R16: 150R; R0402
R12: 2R; R0402
R22: 0.01R; R2512
U1: ADS1015IDGSR; SOP50P490X110-10N
U$1, U$2: 1.27_MALE_16P_HEADER
U$91: 1uH; NRS5040T3R3NMGJ

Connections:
3V3: C2.1, C3.1, C18.1, C28.1, C41.1, C43.1, IC2.4 (VDD), IC3.1 (VOUT_1), IC3.2 (VOUT_2), IC3.4 (FB), IC5.4 (ADD0), IC5.5 (V+), IC9.4 (VS), R2.2, R7.2, U1.8 (VDD), U$2.P$14
5V: C36.1, C39.1, IC4.8 (VIN), R12.1, U$1.P$15, U$1.P$16
ADS_RDY: U1.2 (ALERT/RDY)
AIN0: U1.4 (AIN0), U$1.P$3
AIN1: U1.5 (AIN1), U$1.P$4
AIN2: U1.6 (AIN2), U$1.P$11
AIN3: U1.7 (AIN3), U$1.P$10
BATTERY: C37.1, D15.C, IC9.1 (IN+), R4.2, R6.2, R22.2, U$1.P$12, U$1.P$13, U$91.P$1
BAT_OUT: IC6.5 (D_1), IC6.6 (D_2), IC6.7 (D_3), IC6.8 (D_4), IC6.9 (D_5), U$2.P$1, U$2.P$2
BTAP: C1.1, C40.1, IC1.3 (VCC), IC3.7 (VIN_1), IC3.8 (VIN_2), IC6.1 (S_1), IC6.2 (S_2), IC6.3 (S_3), IC9.2 (IN-), R1.1, R14.2, R22.1
GND: C1.2, C2.2, C3.2, C18.2, C28.2, C35.2, C36.2, C37.2, C38.2, C39.2, C40.2, C41.2, C43.2, D15.A, IC1.1 (GND), IC2.3 (GND), IC2.21 (EP), IC3.3 (LCON), IC3.5 (GND_1), IC3.9 (GND_2), IC4.9 (GND), IC5.2 (GND), IC9.3 (GND), IC9.7 (A0), IC9.8 (A1), LED1_CHRG.C, LED2_FULL.C, LED_BUILTIN.C, Q1.2 (S), R3.1, R5.2, R13.1, U1.1 (ADDR), U1.3 (GND), U$1.P$14, U$2.P$3, U$2.P$4, U$2.P$7, U$2.P$8
I2C_CLK: IC2.14 (PB0), IC5.1 (SCL), IC9.5 (SCL), R2.1, U1.10 (SCL), U$2.P$5
I2C_SDA: IC2.13 (PB1), IC5.6 (SDA), IC9.6 (SDA), R7.1, U1.9 (SDA), U$2.P$6
LED_BUILTIN: IC2.1 (PA2), R8.2
unnamed: Q1.1 (G), R9.2, R13.2
unnamed: LED_BUILTIN.A, R8.1
unnamed: IC6.4 (G), R16.2
unnamed: IC4.6 (ICHG), R3.2
unnamed: C35.1, R12.2
unnamed: LED1_CHRG.A, R10.1
unnamed: LED2_FULL.A, R11.1
unnamed: IC4.4 (NTC), R5.1
unnamed: IC4.2 (TEST), R6.1
unnamed: IC4.1 (D1), R10.2
unnamed: IC4.3 (D2), R11.2
unnamed: C38.1, IC4.5 (BAT), R4.1
unnamed: IC4.7 (SW), U$91.P$2
PA1: IC2.20 (PA1), U$2.P$10
PA3: IC2.2 (EXTCLK_/PA3), U$2.P$9
PA4: IC2.5 (PA4), U$1.P$9
PA5: IC2.6 (PA5), U$1.P$8
PB2: IC2.12 (PB2/TOSC2), U$1.P$1
PB3: IC2.11 (PB3/TOSC1), U$1.P$2
PB4: IC2.10 (PB4), U$1.P$5
PB5: IC2.9 (PB5), U$1.P$6
PC0: IC2.15 (PC0), U$2.P$16
PC1: IC2.16 (PC1), U$2.P$15
PC2: IC2.17 (PC2), U$2.P$13
PC3: IC2.18 (PC3), U$2.P$12
PWR_SW: IC2.8 (PA7), U$1.P$7
P_ON: IC2.7 (PA6), R9.1
P_ON_DS: Q1.3 (D), R14.1, R16.1
SPC_EN: IC1.2 (!RESET), IC3.6 (EN), R1.2
UPDI: IC2.19 (PA0/!RESET!/UPDI), U$2.P$11

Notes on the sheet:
BATTERY AND POWER MANAGEMENT MODULE
NAME
AUTHOR
DATE
EDRTECH D.O.O.
29.07.2024.
active low
current sense resistor
to system
LD56100DPU33R
APX803D

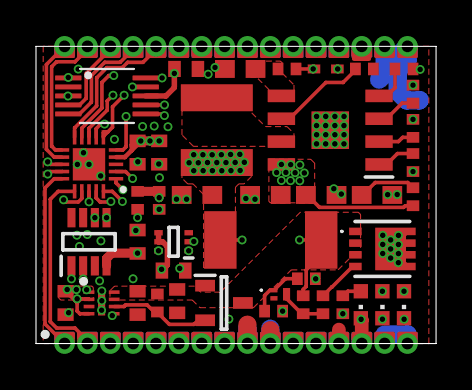
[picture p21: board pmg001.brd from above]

Board: 6 copper layers, 22.2 x 16.5 mm, 45 parts (0 on the bottom side), 43 nets.

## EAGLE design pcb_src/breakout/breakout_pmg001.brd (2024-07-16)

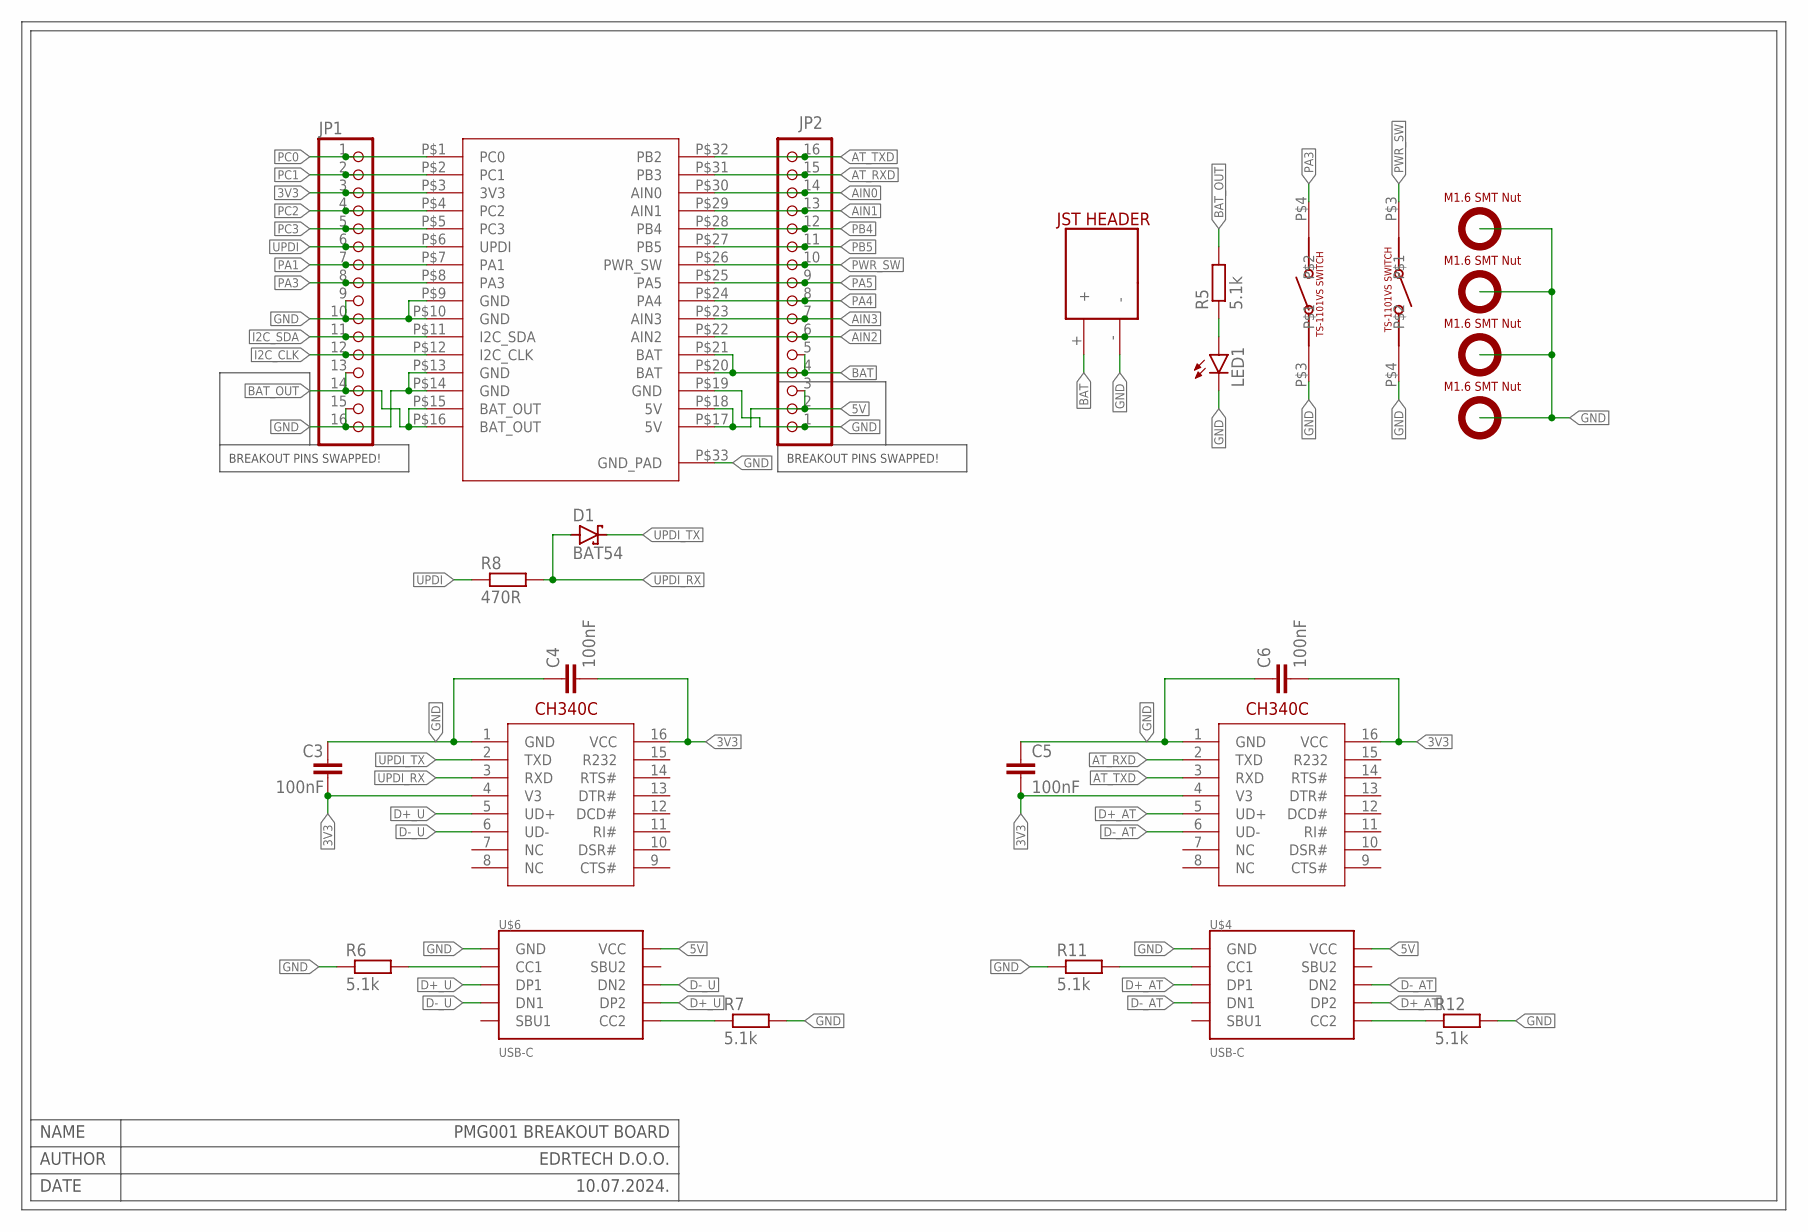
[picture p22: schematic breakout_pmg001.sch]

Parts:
C3, C4, C5, C6: 100nF; C0603
D1: BAT54; SOT23
JP1, JP2: PINHD-1X16; 1X16
LED1: LEDCHIPLED_1206; CHIPLED_1206
R5, R6, R7, R11, R12: 5.1k; R0603
R8: 470R; R0603
SPEAKER_CON1: JST_HEADER_2MM_2P; JST_HEADER
U$1, U$5: CH340C
U$2, U$3: TS-1101VS-C-A-A
U$4, U$6: USB-C
U$7: PMG001
U$8, U$9, U$10, U$11: SMTSO16

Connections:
3V3: C3.2, C4.2, C5.2, C6.2, JP1.3, U$1.4 (V3), U$1.16 (VCC), U$5.4 (V3), U$5.16 (VCC), U$7.P$3 (3V3)
5V: JP2.2, JP2.3, U$4.VCC@1 (VCC), U$4.VCC@2 (VCC), U$6.VCC@1 (VCC), U$6.VCC@2 (VCC), U$7.P$17 (5V), U$7.P$18 (5V)
AIN0: JP2.14, U$7.P$30 (AIN0)
AIN1: JP2.13, U$7.P$29 (AIN1)
AIN2: JP2.6, U$7.P$22 (AIN2)
AIN3: JP2.7, U$7.P$23 (AIN3)
AT_RXD: JP2.15, U$1.2 (TXD), U$7.P$31 (PB3)
AT_TXD: JP2.16, U$1.3 (RXD), U$7.P$32 (PB2)
BAT: JP2.4, JP2.5, SPEAKER_CON1.+, U$7.P$20 (BAT), U$7.P$21 (BAT)
BAT_OUT: JP1.13, JP1.14, R5.2, U$7.P$15 (BAT_OUT), U$7.P$16 (BAT_OUT)
D+_AT: U$1.5 (UD+), U$4.DP1, U$4.DP2
D+_U: U$5.5 (UD+), U$6.DP1, U$6.DP2
D-_AT: U$1.6 (UD-), U$4.DN1, U$4.DN2
D-_U: U$5.6 (UD-), U$6.DN1, U$6.DN2
GND: C3.1, C4.1, C5.1, C6.1, JP1.9, JP1.10, JP1.15, JP1.16, JP2.1, LED1.C, R6.1, R7.2, R11.1, R12.2, SPEAKER_CON1.-, U$1.1 (GND), U$2.P$3, U$3.P$4, U$4.GND@1 (GND), U$4.GND@2 (GND), U$4.P$1 (GND), U$4.P$2 (GND), U$4.P$3 (GND), U$4.P$4 (GND), U$5.1 (GND), U$6.GND@1 (GND), U$6.GND@2 (GND), U$6.P$1 (GND), U$6.P$2 (GND), U$6.P$3 (GND), U$6.P$4 (GND), U$7.P$9 (GND), U$7.P$10 (GND), U$7.P$13 (GND), U$7.P$14 (GND), U$7.P$19 (GND), U$7.P$33 (GND_PAD), U$8.P$1, U$9.P$1, U$10.P$1, U$11.P$1
I2C_CLK: JP1.12, U$7.P$12 (I2C_CLK)
I2C_SDA: JP1.11, U$7.P$11 (I2C_SDA)
unnamed: LED1.A, R5.1
unnamed: R6.2, U$6.CC1
unnamed: R7.1, U$6.CC2
unnamed: R11.2, U$4.CC1
unnamed: R12.1, U$4.CC2
PA1: JP1.7, U$7.P$7 (PA1)
PA3: JP1.8, U$2.P$4, U$7.P$8 (PA3)
PA4: JP2.8, U$7.P$24 (PA4)
PA5: JP2.9, U$7.P$25 (PA5)
PB4: JP2.12, U$7.P$28 (PB4)
PB5: JP2.11, U$7.P$27 (PB5)
PC0: JP1.1, U$7.P$1 (PC0)
PC1: JP1.2, U$7.P$2 (PC1)
PC2: JP1.4, U$7.P$4 (PC2)
PC3: JP1.5, U$7.P$5 (PC3)
PWR_SW: JP2.10, U$3.P$3, U$7.P$26 (PWR_SW)
UPDI: JP1.6, R8.1, U$7.P$6 (UPDI)
UPDI_RX: D1.1 (A), R8.2, U$5.3 (RXD)
UPDI_TX: D1.3 (C), U$5.2 (TXD)

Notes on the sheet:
PMG001 BREAKOUT BOARD
NAME
AUTHOR
DATE
EDRTECH D.O.O.
10.07.2024.
BREAKOUT PINS SWAPPED!

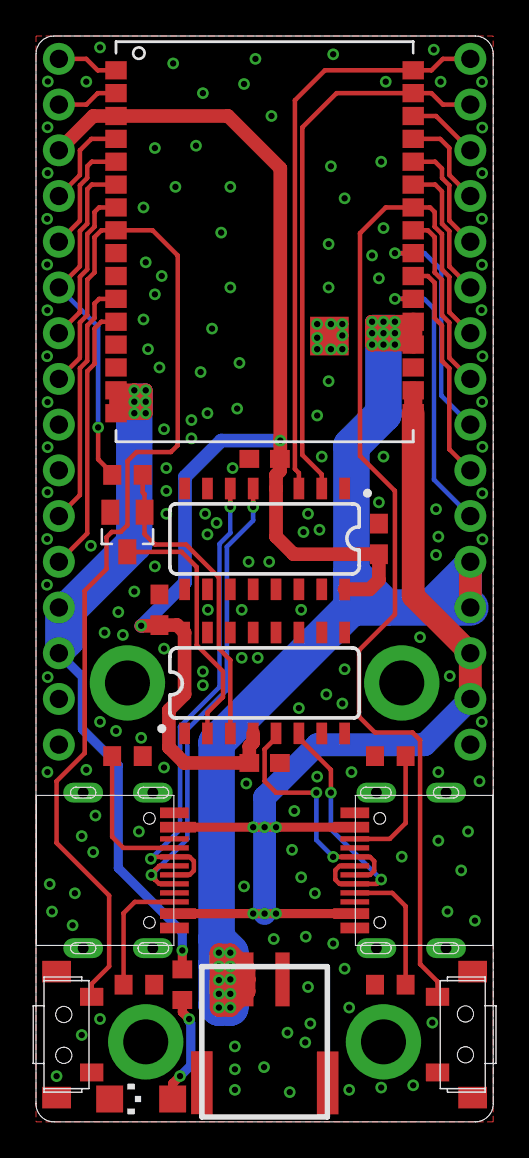
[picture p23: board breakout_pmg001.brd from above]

Board: 2 copper layers, 25.4 x 60.3 mm, 26 parts (0 on the bottom side), 36 nets.

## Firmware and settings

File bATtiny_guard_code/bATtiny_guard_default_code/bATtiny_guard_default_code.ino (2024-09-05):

#include <avr/sleep.h>
#include <avr/interrupt.h>
#include <Wire.h>

#define INA219_ADDRESS 0x40
#define TMP102_ADDRESS 0x49
#define ADS1015_ADDRESS 0x48

volatile uint16_t pa7_timer_count = 0;
volatile uint16_t pa3_timer_count = 0;
volatile bool pa7_pressed = false;
volatile bool pa3_pressed = false;
volatile bool pa7_handled = false;
volatile bool pa3_handled = false;

void setup() {
  Serial.begin(115200);
  while (RTC.STATUS > 0)
    {
        ;  // Wait for all registers to be synchronized
    }
  RTC.CLKSEL = RTC_CLKSEL_INT32K_gc;  // 32.768kHz Internal Ultra-Low-Power Oscillator (OSCULP32K)
  RTC.PITINTCTRL = RTC_PI_bm;  // PIT Interrupt: enabled
  RTC.PITCTRLA = RTC_PERIOD_CYC32768_gc | RTC_PITEN_bm;  // Enable PIT counter: enabled 

  PORTA.DIRCLR = PIN7_bm | PIN3_bm;  
  PORTA.PIN7CTRL = PORT_PULLUPEN_bm | PORT_ISC_BOTHEDGES_gc;
  PORTA.PIN3CTRL = PORT_PULLUPEN_bm | PORT_ISC_BOTHEDGES_gc;

  PORTA.DIRSET = PIN2_bm | PIN6_bm;
  PORTA.OUTCLR = PIN2_bm;  // PA2 initially off
  PORTA.OUTCLR = PIN6_bm;  // PA6 initially off

  cli();

  takeOverTCA0();  // Ensure control of TCA0 timer

  // Configure TCA0 for 100ms interval
  TCA0.SINGLE.CTRLA = TCA_SINGLE_CLKSEL_DIV64_gc;  
  TCA0.SINGLE.PER = 1562;  // 100ms with 10MHz clock and 64 prescaler
  TCA0.SINGLE.CTRLA |= TCA_SINGLE_ENABLE_bm; // Enable the timer
  TCA0.SINGLE.INTCTRL = TCA_SINGLE_OVF_bm;   // Enable overflow interrupt

  sei();
  Wire.begin();
  set_sleep_mode(SLEEP_MODE_STANDBY);  // Set sleep mode to standby
}

void loop() {
  // Enter standby mode when idle
  if (!pa7_pressed && !pa3_pressed) {
    sleep_mode();  // Enter standby mode
  }
}

ISR(PORTA_PORT_vect) {

  // Debounce delay
  delay(10);

  if (PORTA.INTFLAGS & PIN7_bm) {
    pa7_pressed = !(PORTA.IN & PIN7_bm); // LOW when pressed

    if (pa7_pressed) {
      pa7_timer_count = 0; // Start counting when button is pressed
      pa7_handled = false; // Reset action flag
    }
    PORTA.INTFLAGS = PIN7_bm;
  }

  if (PORTA.INTFLAGS & PIN3_bm) {
    pa3_pressed = !(PORTA.IN & PIN3_bm); // LOW when pressed

    if (pa3_pressed) {
      pa3_timer_count = 0; // Start counting when button is pressed
      pa3_handled = false; // Reset action flag
    }
    PORTA.INTFLAGS = PIN3_bm;
  }
  Serial.flush();
}

ISR(TCA0_OVF_vect) {
  TCA0.SINGLE.INTFLAGS = TCA_SINGLE_OVF_bm;

  // PA7 tracking
  if (pa7_pressed && !pa7_handled) {
    pa7_timer_count++;

    if (!(PORTA.OUT & PIN6_bm) && pa7_timer_count >= 20) { // PA6 is off, 200ms
      PORTA.OUTSET = PIN6_bm; // Turn PA6 on (LOW state)

      pa7_handled = true; // Mark action as handled
    } else if ((PORTA.OUT & PIN6_bm) && pa7_timer_count >= 300) { // PA6 is on, 3s
      PORTA.OUTCLR = PIN6_bm; // Turn PA6 off (HIGH state)

      pa7_handled = true; // Mark action as handled
    }
  }

  // PA3 tracking
  if (pa3_pressed && !pa3_handled) {
    pa3_timer_count++;

    if (pa3_timer_count >= 2) {  // 200ms
      PORTA.OUTTGL = PIN2_bm; // Toggle PA2
      pa3_handled = true; // Mark action as handled
    }
  }

  // Reset timer counts when buttons are released
  if (!pa7_pressed) {
    pa7_timer_count = 0;
  }
  if (!pa3_pressed) {
    pa3_timer_count = 0;
  }
}

ISR(RTC_PIT_vect) 
{
    RTC.PITINTFLAGS = RTC_PI_bm;  // Clear interrupt flag by writing '1' (required)
    float tbuf = readTMP102();
    float ain0buf = ADS1015_readChannel(0);
    float ain1buf = ADS1015_readChannel(1);
    float ain2buf = ADS1015_readChannel(2);
    float ain3buf = ADS1015_readChannel(3);
    float bvbuf = INA219_readBV();
    float svbuf = INA219_readSV();
    float bcbuf = INA219_readC();

    Serial.write(12);  // Clear screen and move cursor to home
     String output = "";  // Clear screen and move cursor to home
    output += "-----------------------------------\r\n";
    output += "TMP102 Temperature:      ";
    output += String(tbuf, 2);
    output += "°C\r\n";
    output += "-----------------------------------\r\n";
    output += "ADS1015 AIN0:            ";
    output += String(ain0buf, 4);
    output += "V\r\n";
    output += "ADS1015 AIN1:            ";
    output += String(ain1buf, 4);
    output += "V\r\n";
    output += "ADS1015 AIN2:            ";
    output += String(ain2buf, 4);
    output += "V\r\n";
    output += "ADS1015 AIN3:            ";
    output += String(ain3buf, 4);
    output += "V\r\n";
    output += "-----------------------------------\r\n";
    output += "INA219 Battery voltage:  ";
    output += String(bvbuf, 4);
    output += "V\r\n";
    output += "INA219 Shunt voltage:    ";
    output += String(svbuf, 4);
    output += "mV\r\n";
    output += "INA219 Battery current:  ";
    output += String(bcbuf, 4);
    output += "mA\r\n";
    output += "-----------------------------------\r\n";
    output += "PWR_SW:  ";
    output += String(!digitalRead(PIN_PA7));
    output += "\r\n";
    output += "PA3_SW:  ";
    output += String(!digitalRead(PIN_PA3));
    output += "\r\n";
    output += "BAT_OUT:  ";
    output += String(digitalRead(PIN_PA6));
    output += "\r\n";
    output += "LED_BUILTIN:  ";
    output += String(digitalRead(PIN_PA2));
    output += "\r\n";
    output += "-----------------------------------\r\n";
    Serial.print(output);

    Serial.flush();
}

void INA219_setCal() 
{
    uint16_t calByte = 4096;  // Calibration register value
    uint16_t configBytes = 0b0011100110011111;  // Configuration register value

    Wire.beginTransmission(INA219_ADDRESS);
    Wire.write(0x05);  // Calibration register address
    Wire.write((uint8_t)(calByte >> 8));  // High byte
    Wire.write((uint8_t)(calByte & 0xFF));  // Low byte
    Wire.endTransmission();

    Wire.beginTransmission(INA219_ADDRESS);
    Wire.write(0x00);  // Configuration register address
    Wire.write((uint8_t)(configBytes >> 8));  // High byte
    Wire.write((uint8_t)(configBytes & 0xFF));  // Low byte
    Wire.endTransmission();
}

float INA219_readBV() 
{
    uint16_t busVoltReg = 0x00;
    INA219_setCal();

    Wire.beginTransmission(INA219_ADDRESS);
    Wire.write(0x02);  // Bus voltage register address
    Wire.endTransmission();

    Wire.requestFrom(INA219_ADDRESS, 2);
    if (Wire.available() == 2) 
    {
        busVoltReg = (Wire.read() << 8) | Wire.read();
    }

    return ((busVoltReg >> 3) * 0.001) * 4;
}

float INA219_readSV() 
{
    uint16_t shuntVoltReg = 0x00;
    INA219_setCal();

    Wire.beginTransmission(INA219_ADDRESS);
    Wire.write(0x01);  // Shunt voltage register address
    Wire.endTransmission();

    Wire.requestFrom(INA219_ADDRESS, 2);
    if (Wire.available() == 2) 
    {
        shuntVoltReg = (Wire.read() << 8) | Wire.read();
    }

    return shuntVoltReg * 0.1;
}

float INA219_readC() 
{
    uint16_t currentReg = 0x00;
    INA219_setCal();

    Wire.beginTransmission(INA219_ADDRESS);
    Wire.write(0x04);  // Current register address
    Wire.endTransmission();

    Wire.requestFrom(INA219_ADDRESS, 2);
    if (Wire.available() == 2) 
    {
        currentReg = (Wire.read() << 8) | Wire.read();
    }

    return currentReg;
}

float readTMP102() 
{
    int16_t dTemp;
    Wire.beginTransmission(TMP102_ADDRESS);
    Wire.write(0X00);  // Temperature register address
    Wire.endTransmission();

    uint8_t regByte[2];
    Wire.requestFrom(TMP102_ADDRESS, 2);
    regByte[0] = Wire.read();
    regByte[1] = Wire.read();

    dTemp = ((regByte[0]) << 4) | (regByte[1] >> 4);
    if (dTemp > 0x7FF) 
    {
        dTemp |= 0xF000;
    }
    return dTemp * 0.0625;
}

float ADS1015_readChannel(uint8_t channel) 
{
    uint16_t mux;
    switch (channel) 
    {
        case 0: mux = 0x4000; break;
        case 1: mux = 0x5000; break;
        case 2: mux = 0x6000; break;
        case 3: mux = 0x7000; break;
        default: return -1;
    }

    uint16_t configBytes = 0x0000 | 0x0200 | mux | 0x0080 | 0x8000;
    uint16_t voltReg = 0x00;

    Wire.beginTransmission(ADS1015_ADDRESS);
    Wire.write(0x01);  // Configuration register address
    Wire.write((uint8_t)(configBytes >> 8));  // High byte
    Wire.write((uint8_t)(configBytes & 0xFF));  // Low byte
    Wire.endTransmission();

    delay(10);  // Wait for conversion to complete

    Wire.beginTransmission(ADS1015_ADDRESS);
    Wire.write(0x00);  // Conversion register address
    Wire.endTransmission();

    Wire.requestFrom(ADS1015_ADDRESS, 2);
    if (Wire.available() == 2) 
    {
        voltReg = (Wire.read() << 8) | Wire.read();
    }

    return (voltReg >> 4) * (4.096f / (32768 >> 4));
}

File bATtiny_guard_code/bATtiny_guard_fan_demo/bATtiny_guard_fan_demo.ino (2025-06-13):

#include <avr/sleep.h>
#include <avr/interrupt.h>
#include <Wire.h>
#include <megaTinyCore.h>

#define FAN_PIN     PIN_PA6

#define SW1_PIN     PIN_PA3
#define SW2_PIN     PIN_PC2
#define RESET_PIN   PIN_PC3

#define LED_FAULT_PIN  PIN_PA1
#define LED_WARN_PIN   PIN_PA4
#define LED_OK_PIN     PIN_PA5

#define INA219_ADDRESS 0x40
#define TMP102_ADDRESS 0x49
#define ADS1015_ADDRESS 0x48

bool fan_enabled = false;
bool fault_active = false;

float current_threshold = 160.0f;

float currentBuffer[3] = {0};
uint8_t currentIndex = 0;
bool bufferFilled = false;

unsigned long fanStartTime = 0;

bool sw1Prev = true;
bool sw2Prev = true;
bool resetPrev = true;

unsigned long lastReport = 0;
const unsigned long reportInterval = 1000;

void INA219_setCal() 
{
  uint16_t calByte = 4096;
  uint16_t configBytes = 0b0011100110011111;

  Wire.beginTransmission(INA219_ADDRESS);
  Wire.write(0x05);
  Wire.write((uint8_t)(calByte >> 8));
  Wire.write((uint8_t)(calByte & 0xFF));
  Wire.endTransmission();

  Wire.beginTransmission(INA219_ADDRESS);
  Wire.write(0x00);
  Wire.write((uint8_t)(configBytes >> 8));
  Wire.write((uint8_t)(configBytes & 0xFF));
  Wire.endTransmission();
}

float INA219_readBV() 
{
  uint16_t busVoltReg = 0x00;
  INA219_setCal();

  Wire.beginTransmission(INA219_ADDRESS);
  Wire.write(0x02);
  Wire.endTransmission();

  Wire.requestFrom(INA219_ADDRESS, 2);
  if (Wire.available() == 2) 
  {
    busVoltReg = (Wire.read() << 8) | Wire.read();
  }

  return ((busVoltReg >> 3) * 0.001) * 4;
}

float INA219_readSV() 
{
  uint16_t shuntVoltReg = 0x00;
  INA219_setCal();

  Wire.beginTransmission(INA219_ADDRESS);
  Wire.write(0x01);
  Wire.endTransmission();

  Wire.requestFrom(INA219_ADDRESS, 2);
  if (Wire.available() == 2) {
    shuntVoltReg = (Wire.read() << 8) | Wire.read();
  }

  return shuntVoltReg * 0.1;
}

float INA219_readC() 
{
  uint16_t currentReg = 0x00;
  INA219_setCal();

  Wire.beginTransmission(INA219_ADDRESS);
  Wire.write(0x04);
  Wire.endTransmission();

  Wire.requestFrom(INA219_ADDRESS, 2);
  if (Wire.available() == 2) 
  {
    currentReg = (Wire.read() << 8) | Wire.read();
  }

  return currentReg;
}

float readTMP102() 
{
  int16_t dTemp;
  Wire.beginTransmission(TMP102_ADDRESS);
  Wire.write(0x00);
  Wire.endTransmission();

  uint8_t regByte[2];
  Wire.requestFrom(TMP102_ADDRESS, 2);
  regByte[0] = Wire.read();
  regByte[1] = Wire.read();

  dTemp = ((regByte[0]) << 4) | (regByte[1] >> 4);
  if (dTemp > 0x7FF) 
  {
    dTemp |= 0xF000;
  }
  return dTemp * 0.0625;
}

float ADS1015_readChannel(uint8_t channel) 
{
  uint16_t mux;
  switch (channel) 
  {
    case 0: mux = 0x4000; break;
    case 1: mux = 0x5000; break;
    case 2: mux = 0x6000; break;
    case 3: mux = 0x7000; break;
    default: return -1;
  }

  uint16_t configBytes = 0x0000 | 0x0200 | mux | 0x0080 | 0x8000;
  uint16_t voltReg = 0x00;

  Wire.beginTransmission(ADS1015_ADDRESS);
  Wire.write(0x01);
  Wire.write((uint8_t)(configBytes >> 8));
  Wire.write((uint8_t)(configBytes & 0xFF));
  Wire.endTransmission();

  delay(10);

  Wire.beginTransmission(ADS1015_ADDRESS);
  Wire.write(0x00);
  Wire.endTransmission();

  Wire.requestFrom(ADS1015_ADDRESS, 2);
  if (Wire.available() == 2) 
  {
    voltReg = (Wire.read() << 8) | Wire.read();
  }

  return (voltReg >> 4) * (4.096f / (32768 >> 4));
}

void setup() 
{
  Serial.begin(115200);
  Wire.begin();

  pinMode(FAN_PIN, OUTPUT);
  digitalWrite(FAN_PIN, LOW);

  pinMode(SW1_PIN, INPUT_PULLUP);
  pinMode(SW2_PIN, INPUT_PULLUP);
  pinMode(RESET_PIN, INPUT_PULLUP);

  pinMode(LED_OK_PIN, OUTPUT);
  pinMode(LED_WARN_PIN, OUTPUT);
  pinMode(LED_FAULT_PIN, OUTPUT);

  digitalWrite(LED_OK_PIN, LOW);
  digitalWrite(LED_WARN_PIN, LOW);
  digitalWrite(LED_FAULT_PIN, LOW);
}

void loop() 
{
  float current_mA = INA219_readC();
  float bvbuf = INA219_readBV();
  float svbuf = INA219_readSV();
  float tbuf = readTMP102();
  float pot_voltage = ADS1015_readChannel(2);

  if (pot_voltage >= 0.0f && pot_voltage <= 3.3f) 
  {
    current_threshold = 160.0f + ((pot_voltage / 3.3f) * (250.0f - 160.0f));
  }

  bool sw1Now = digitalRead(SW1_PIN);
  bool sw2Now = digitalRead(SW2_PIN);
  bool resetNow = digitalRead(RESET_PIN);

  if (sw1Prev && !sw1Now && !fault_active) 
  {
    fan_enabled = !fan_enabled;
    if (fan_enabled) 
    {
      fanStartTime = millis();
    }
  }
  if (sw2Prev && !sw2Now && !fault_active) 
  {
    fan_enabled = !fan_enabled;
    if (fan_enabled) 
    {
      fanStartTime = millis();
    }
  }

  if (resetPrev && !resetNow) 
  {
    fault_active = false;
    digitalWrite(LED_FAULT_PIN, LOW);
  }

  sw1Prev = sw1Now;
  sw2Prev = sw2Now;
  resetPrev = resetNow;

  digitalWrite(FAN_PIN, fan_enabled ? HIGH : LOW);

  currentBuffer[currentIndex] = current_mA;
  currentIndex = (currentIndex + 1) % 3;
  if (currentIndex == 0) bufferFilled = true;

  float avg_current = 0.0;
  int count = bufferFilled ? 3 : currentIndex;
  for (int i = 0; i < count; ++i) 
  {
    avg_current += currentBuffer[i];
  }
  avg_current /= count;

  bool ignore_current = (millis() - fanStartTime < 1000);

  if (fan_enabled && !fault_active) 
  {
    if (!ignore_current) 
    {
      if (avg_current < 120.0f) 
      {
        digitalWrite(LED_OK_PIN, HIGH);
        digitalWrite(LED_WARN_PIN, LOW);
        digitalWrite(LED_FAULT_PIN, LOW);
      }
      else if (avg_current < current_threshold) 
      {
        digitalWrite(LED_OK_PIN, HIGH);
        digitalWrite(LED_WARN_PIN, HIGH);
        digitalWrite(LED_FAULT_PIN, LOW);
      } else 
      {
        fault_active = true;
        fan_enabled = false;
        digitalWrite(FAN_PIN, LOW);
        digitalWrite(LED_FAULT_PIN, HIGH);
        digitalWrite(LED_OK_PIN, LOW);
        digitalWrite(LED_WARN_PIN, LOW);
      }
    } 
    else 
    {
      digitalWrite(LED_OK_PIN, HIGH);
      digitalWrite(LED_WARN_PIN, LOW);
      digitalWrite(LED_FAULT_PIN, LOW);
    }
  }

  if (!fan_enabled) 
  {
    digitalWrite(LED_OK_PIN, LOW); // Turn off green LED when fan is off
    digitalWrite(LED_WARN_PIN, LOW);
  }

  if (millis() - lastReport > reportInterval) 
  {
    lastReport = millis();
    Serial.write(12);  // Clear terminal
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

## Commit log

2024-07-16 Added BOMs
    BOM for module added
    Bom for demo kit added
2024-08-01 Module and cover board revised. Datasheet revised. Code added.
    Updated with one additional component, added cutout to cover board. Updated documentation accordingly. Added default program.
    [cover_breakout_pmg001.brd, cover_breakout_pmg001.sch, footprint_Model.dxf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]
2024-08-01 I2C Adress corrected
    Corrected I2C address of ADS1015
2024-08-01 Added arduino ide board settings
2024-08-01 Added schematics
    white background
2024-08-05 Updated BOM
    Replaced/added some components
2024-08-24 Power saving features added
    Wake up from power down mode every 5 seconds to take measurements.
    Wake up on button interrupt.
    This realizes big power saving gains as the CPU is powered down most of the time.
2024-08-25 Added Symbol/footprint libraries
    EAGLE and KiCad
2024-08-26 Reworked firmware for power saving
    Now works almost exclusively based on interrupts, cpu is in standby mode to reduce power consumption when not running.
2024-08-30 Switched to Cern OHL-P License
2024-09-05 Updated firmware, added layers document
    Firmware updated to match hardware.
    Added PDF with PCB layers.
2025-06-06 Added KiCAD conversion
    [bATtiny_guard_PMG001_module.kicad_pcb, bATtiny_guard_PMG001_module.kicad_sch]
2025-06-13 Added fan current demo code
